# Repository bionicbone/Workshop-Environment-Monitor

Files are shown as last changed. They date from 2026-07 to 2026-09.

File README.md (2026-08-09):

# Workshop Environment Monitor (WEM)

An open-source ESP32-S3 based air quality and environmental monitor, built for workshops where 3D printing, soldering, and other fume-producing work happens in an enclosed space.

WEM continuously measures CO2, TVOC, HCHO (formaldehyde), particulates, temperature and humidity, displays live readings on a 7" touchscreen (if fitted), and publishes everything to [Home Assistant](https://www.home-assistant.io/) over MQTT for logging, automation and alerting.

This project exists because 3D printing ABS and soldering in a workshop produces measurable off-gassing and fumes — WEM was built to quantify that, and to benchmark a custom venting system against real data rather than guesswork.

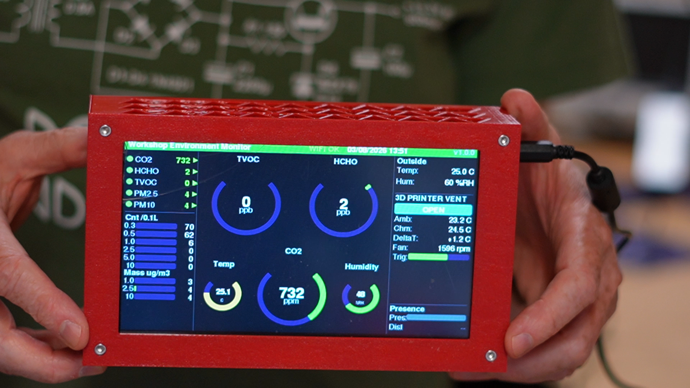
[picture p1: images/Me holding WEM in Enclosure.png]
WEM with Enclosure showing live sensor gauges


---

## Quality, and modular

These two ideas pull against each other, and how WEM resolves that is the main thing worth understanding about the design.

**Quality first.** WEM uses good sensors rather than the cheapest ones that will fit the footprint. A monitor that reports comfortable numbers while the air is actually bad is worse than no monitor at all — you'd act on it. That rules out the bargain modules, and it means a full build isn't cheap.

**So the build is modular.** Every sensor is optional, and so is the touchscreen. WEM probes what's connected at boot and adapts: absent hardware is excluded from the display, from the alarms, and from Home Assistant, with no code changes, no build flags, and nothing to configure.

The practical upshot: **start with the sensors that matter most to you and add the rest as you can afford them.** A WEM with two sensors and no screen is a legitimate build, not a broken one — and adding a sensor later is a matter of plugging it in and restarting.

## YouTube

Workshop Fumes Are Invisible — I Built a Monitor to See Them (https://youtu.be/jspVboeYZX0)

---

## Getting started

Everything you need is here: the firmware, the vendored libraries it builds against, the hardware design files, and a full [`USER_GUIDE.md`](USER_GUIDE.md) covering building, flashing, first boot and configuration.

**v1.0.0 is a compile-it-yourself release.** A compiled image has your WiFi and MQTT credentials baked into it, so there's no shared binary to download — you build the firmware from source against your own `secrets.h` and flash it to the ESP32-S3. [`USER_GUIDE.md`](USER_GUIDE.md) walks through the whole process, including the exact board settings and the vendored libraries you must build against.

A way to enter WiFi/MQTT details on the device at first boot is planned as a fast-follow — after which pre-built binaries can be published too.

---

## What it monitors

| Sensor | Measures | Interface |
|---|---|---|
| SGP30 | TVOC (total volatile organic compounds) | I2C |
| SFA40 | HCHO (formaldehyde) | UART |
| SCD40 | CO2 | I2C |
| SHT40 | Temperature / humidity (primary) | I2C |
| BME280 | Temperature / humidity (secondary, HA-only) | I2C |
| PMS5003 | Particulates — see below | UART |
| LD2410B | mmWave presence detection | UART |

### Particulates, in detail

The PMS5003 reports particulates two ways, and WEM publishes all nine channels to Home Assistant and to the display:

- **Particle counts** (cnt/0.1L) at **0.3, 0.5, 1.0, 2.5, 5.0 and 10 µm**
- **Mass concentrations** (µg/m³) at **PM1.0, PM2.5 and PM10**

**PM0.3 and PM0.5 are the ones to watch for 3D printing.** Ultrafine particles from a hot nozzle are numerous but individually almost weightless, so they can be present in large numbers while the mass figures still read close to zero. A monitor reporting only µg/m³ would tell you the air was fine. That's exactly the false-comfort problem the count channels exist to prevent — and a good illustration of why sensor choice matters more than sensor price.

Readings are shown on a 7" 800×480 SSD1963 TFT touchscreen (if fitted) with live gauges, and published to Home Assistant via [ArduinoHA](https://github.com/dawidchyrzynski/arduino-home-assistant) over MQTT.

---

## Running without a display

The touchscreen is optional on the same terms as the sensors — leave it off and WEM runs headless, reading every sensor and publishing to Home Assistant exactly as it otherwise would. It's the single biggest cost saving available, and a sensible build if you already live in the HA dashboard or you're mounting the unit somewhere nobody will look at it.

Two things to know before choosing that route: touch is currently WEM's only input, so a headless build **can't snooze an active alarm** and **can't clear the SGP30 calibration baseline**. Both will be exposed as Home Assistant buttons shortly after release. `USER_GUIDE.md` covers this fully.

---

## Repository structure

```
├── Workshop Environment Monitor/   Arduino sketch — the firmware source
├── hardware/                  PCB design files (Gerbers), STEP model, hardware README
│                              (attribution / Source Location notice), Bill of Materials,
│                              display manufacturer datasheet, breakout-board references
│                              (photos/links being added post-launch)
├── Libraries/                 Full vendored copies of every Arduino library WEM
│                              depends on, exactly as used to build and test it
├── stl for printing/          3D-printable enclosure and sensor mount STL files
├── images/                    Images used by the README, user guide and Bill of Materials
├── USER_GUIDE.md              Build, flash, first-boot and configuration guide
├── LICENSE                    Firmware licence (AGPL-3.0-or-later)
├── LICENSE-hardware.txt       Hardware licence (CERN-OHL-W-2.0)
├── THIRD_PARTY_LICENSES.md    Full attribution and licence text for every dependency
└── secrets.h.example          Template for your own WiFi/MQTT credentials
```

Copy `secrets.h.example` to `secrets.h` in the sketch folder and add your own WiFi/MQTT credentials before building — `secrets.h` is git-ignored and must never be committed. The user guide covers this.

---

## Building the PCB

Gerber files for the WEM main PCB are in [`hardware/`](hardware). To get boards made:

1. Download the Gerber `.zip` from `hardware/`.
2. Upload it directly to a fab house's quoting page — [JLCPCB](https://jlcpcb.com/).
3. Default settings (1.6mm thickness, HASL finish, 1oz copper) match what this design was built and tested with; nothing exotic is required.

Breakout-board module links and assembly photos are being put together for a launch video and will be added to `hardware/` shortly after release — see the note in that folder.

---

## Licensing

- **Firmware**: [AGPL-3.0-or-later](LICENSE) — required because WEM links against ArduinoHA, which is itself AGPL-3.0. See [`THIRD_PARTY_LICENSES.md`](THIRD_PARTY_LICENSES.md) for the full rationale and every dependency's licence.
- **Hardware (PCB + enclosure)**: [CERN-OHL-W-2.0](LICENSE-hardware.txt).

Full attribution for every third-party library, with verbatim licence text, is in [`THIRD_PARTY_LICENSES.md`](THIRD_PARTY_LICENSES.md).

---

## Why "Workshop" Environment Monitor?

Built to answer a simple question: is my workshop air actually safe to breathe while I'm printing ABS or soldering, and does my venting setup actually help? WEM logs real numbers to Home Assistant so that question has a real answer instead of a guess.

---

## Acknowledgements

Built with [ArduinoHA](https://github.com/dawidchyrzynski/arduino-home-assistant), [TFT_eSPI](https://github.com/Bodmer/TFT_eSPI), and sensor libraries from Adafruit and Sensirion. Full credits in [`THIRD_PARTY_LICENSES.md`](THIRD_PARTY_LICENSES.md).

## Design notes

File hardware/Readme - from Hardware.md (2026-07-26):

SPDX-License-Identifier: CERN-OHL-W-2.0

Copyright (C) 2026 Kevin Guest (BionicBone)

This documentation describes Open Hardware and is licensed under the
CERN-OHL-W v2 or any later version.

You may redistribute and modify this documentation and make products using it
under the terms of the CERN-OHL-W v2 (https://ohwr.org/cern-ohl-w-v2). This
documentation is distributed WITHOUT ANY EXPRESS OR IMPLIED WARRANTY, INCLUDING
OF MERCHANTABILITY, SATISFACTORY QUALITY AND FITNESS FOR A PARTICULAR PURPOSE.
Please see the CERN-OHL-W v2 for applicable conditions.

Source Location: https://github.com/bionicbone/Workshop-Environment-Monitor

---

Third-Party Material
---------------------

This folder includes the manufacturer datasheet for the TFT display module
used in this project. The datasheet is included for reference only, to help
builders identify and order the correct display variant (voltage, interface,
connector and options vary between otherwise similar-looking modules). It is
not authored by, and is not part of, the Covered Source above, and remains
the copyright of its original manufacturer. It is not licensed under
CERN-OHL-W-2.0.

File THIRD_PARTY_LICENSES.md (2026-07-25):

# Third-Party Licenses and Attribution

**Project:** Workshop Environmental Monitor (WEM)
**Copyright (C) 2026 Kevin Guest (TheBionicBone)**
**Project license:** AGPL-3.0-or-later — see [`LICENSE`](LICENSE)

---

## Why this project is AGPL-3.0

WEM links against **ArduinoHA** (`home-assistant-integration`), which is
distributed under the **GNU Affero General Public License v3.0**. Linking
produces a single combined work, so the AGPL's copyleft terms extend to the
whole firmware. The entire project is therefore released under AGPL-3.0-or-later.

**What this means for anyone using WEM:**

- You may use, study, modify and redistribute this firmware freely.
- If you distribute it — as source **or** as a compiled `.bin` — you must make
  the complete corresponding source available under the same license.
- Every binary published on this project's GitHub Releases page is accompanied
  by a link to the exact source tag it was built from, satisfying this
  requirement.

---

## Library summary

Versions correspond to those pinned in the Schematic Reference "Software /
Library Reference" table, verified identical under ESP32 Arduino core 2.0.17
and 3.3.10.

| Library | Version | Copyright holder | License |
|---|---|---|---|
| ArduinoHA (`home-assistant-integration`) | 2.1.0 | Dawid Chyrzynski | AGPL-3.0 |
| TFT_eSPI | 2.5.43 | Bodmer | BSD 2-Clause ("FreeBSD") |
| PubSubClient | 2.8 | Nicholas O'Leary | MIT |
| Adafruit SHT4x | 1.0.5 | Adafruit Industries | BSD 3-Clause |
| Adafruit SGP30 | 2.0.3 | Adafruit Industries | BSD 3-Clause |
| Adafruit BME280 | 2.3.0 | Limor Fried & Kevin Townsend, Adafruit Industries | BSD 3-Clause |
| Adafruit PM25AQI | 2.0.0 | Adafruit Industries | BSD 3-Clause |
| Adafruit Unified Sensor | 1.1.15 | Adafruit Industries | Apache-2.0 |
| Adafruit BusIO | 1.17.4 | Adafruit Industries | MIT |
| SensirionI2cScd4x | 1.1.0 | Sensirion AG | BSD 3-Clause |
| Sensirion Core | 0.7.3 | Sensirion AG | BSD 3-Clause |
| ld2410 (`ncmreynolds/ld2410`) | 0.2.2 | Nick Reynolds | LGPL-2.1 |
| ESP32 Arduino core (WiFi, Wire, SPI, FS, SPIFFS, ESPmDNS, ArduinoOTA, Preferences, Update) | 2.0.17 / 3.3.10 | Espressif Systems and contributors | LGPL-2.1-or-later |
| ESP-IDF (underlying SDK) | bundled with core | Espressif Systems | Apache-2.0 |

---

## Obligations, by license family

### AGPL-3.0 (ArduinoHA)
Complete corresponding source of the combined work must be available to
anyone who receives a binary. Satisfied by publishing full source on GitHub
and tagging each release binary against its source commit.

### LGPL-2.1 (ld2410, ESP32 Arduino core)
Source for the LGPL'd components must remain available, and users must be able
to relink the work against a modified version of those components. Satisfied
by publishing full source, documenting exact library and core versions, and
using unmodified upstream libraries. **Note:** if any LGPL library is ever
patched locally, that patched source must be published too.

### BSD 2/3-Clause (TFT_eSPI, Adafruit sensor libraries, Sensirion)
The copyright notice, conditions list and disclaimer must be reproduced in
redistributions — including binary-only ones. Reproduced in full below.

### MIT (PubSubClient, Adafruit BusIO)
The copyright notice and permission notice must be included in all copies or
substantial portions. Reproduced in full below.

### Apache-2.0 (Adafruit Unified Sensor, ESP-IDF)
A copy of the license must be included, any `NOTICE` file contents preserved,
and modified files marked as changed. No files from these components have been
modified in this project.

---

## Full license texts

> Verbatim `LICENSE` text from each upstream repository is reproduced below.
> Where an identical license *document* is shared, it appears once and the
> other users point to it: the GNU LGPL v2.1 text is given once (under ld2410)
> and referenced by the ESP32 core; the Apache-2.0 text is given once (under
> Adafruit Unified Sensor) and referenced by ESP-IDF. Each library's own
> copyright line is reproduced individually regardless.
>
> **Still outstanding before release:** the four Adafruit BSD-3-Clause libraries
> still carry four separate copies of the (identical) Adafruit BSD text — these
> could be consolidated the same way, or left as-is if the per-file Adafruit
> header blocks are being kept deliberately. Re-confirm each text against the
> upstream `LICENSE` at the pinned version, and check the ESP32 core version in
> the summary table (see note there).

### ArduinoHA — AGPL-3.0
Copyright (C) Dawid Chyrzynski
Source: https://github.com/dawidchyrzynski/arduino-home-assistant

                    GNU AFFERO GENERAL PUBLIC LICENSE
                       Version 3, 19 November 2007

 Copyright (C) 2007 Free Software Foundation, Inc. <https://fsf.org/>
 Everyone is permitted to copy and distribute verbatim copies
 of this license document, but changing it is not allowed.

                            Preamble

  The GNU Affero General Public License is a free, copyleft license for
software and other kinds of works, specifically designed to ensure
cooperation with the community in the case of network server software.

  The licenses for most software and other practical works are designed
to take away your freedom to share and change the works.  By contrast,
our General Public Licenses are intended to guarantee your freedom to
share and change all versions of a program--to make sure it remains free
software for all its users.

  When we speak of free software, we are referring to freedom, not
price.  Our General Public Licenses are designed to make sure that you
have the freedom to distribute copies of free software (and charge for
them if you wish), that you receive source code or can get it if you
want it, that you can change the software or use pieces of it in new
free programs, and that you know you can do these things.

  Developers that use our General Public Licenses protect your rights
with two steps: (1) assert copyright on the software, and (2) offer
you this License which gives you legal permission to copy, distribute
and/or modify the software.

  A secondary benefit of defending all users' freedom is that
improvements made in alternate versions of the program, if they
receive widespread use, become available for other developers to
incorporate.  Many developers of free software are heartened and
encouraged by the resulting cooperation.  However, in the case of
software used on network servers, this result may fail to come about.
The GNU General Public License permits making a modified version and
letting the public access it on a server without ever releasing its
source code to the public.

  The GNU Affero General Public License is designed specifically to
ensure that, in such cases, the modified source code becomes available
to the community.  It requires the operator of a network server to
provide the source code of the modified version running there to the
users of that server.  Therefore, public use of a modified version, on
a publicly accessible server, gives the public access to the source
code of the modified version.

  An older license, called the Affero General Public License and
published by Affero, was designed to accomplish similar goals.  This is
a different license, not a version of the Affero GPL, but Affero has
released a new version of the Affero GPL which permits relicensing under
this license.

  The precise terms and conditions for copying, distribution and
modification follow.

                       TERMS AND CONDITIONS

  0. Definitions.

  "This License" refers to version 3 of the GNU Affero General Public License.

  "Copyright" also means copyright-like laws that apply to other kinds of
works, such as semiconductor masks.

  "The Program" refers to any copyrightable work licensed under this
License.  Each licensee is addressed as "you".  "Licensees" and
"recipients" may be individuals or organizations.

  To "modify" a work means to copy from or adapt all or part of the work
in a fashion requiring copyright permission, other than the making of an
exact copy.  The resulting work is called a "modified version" of the
earlier work or a work "based on" the earlier work.

  A "covered work" means either the unmodified Program or a work based
on the Program.

  To "propagate" a work means to do anything with it that, without
permission, would make you directly or secondarily liable for
infringement under applicable copyright law, except executing it on a
computer or modifying a private copy.  Propagation includes copying,
distribution (with or without modification), making available to the
public, and in some countries other activities as well.

  To "convey" a work means any kind of propagation that enables other
parties to make or receive copies.  Mere interaction with a user through
a computer network, with no transfer of a copy, is not conveying.

  An interactive user interface displays "Appropriate Legal Notices"
to the extent that it includes a convenient and prominently visible
feature that (1) displays an appropriate copyright notice, and (2)
tells the user that there is no warranty for the work (except to the
extent that warranties are provided), that licensees may convey the
work under this License, and how to view a copy of this License.  If
the interface presents a list of user commands or options, such as a
menu, a prominent item in the list meets this criterion.

  1. Source Code.

  The "source code" for a work means the preferred form of the work
for making modifications to it.  "Object code" means any non-source
form of a work.

  A "Standard Interface" means an interface that either is an official
standard defined by a recognized standards body, or, in the case of
interfaces specified for a particular programming language, one that
is widely used among developers working in that language.

  The "System Libraries" of an executable work include anything, other
than the work as a whole, that (a) is included in the normal form of
packaging a Major Component, but which is not part of that Major
Component, and (b) serves only to enable use of the work with that
Major Component, or to implement a Standard Interface for which an
implementation is available to the public in source code form.  A
"Major Component", in this context, means a major essential component
(kernel, window system, and so on) of the specific operating system
(if any) on which the executable work runs, or a compiler used to
produce the work, or an object code interpreter used to run it.

  The "Corresponding Source" for a work in object code form means all
the source code needed to generate, install, and (for an executable
work) run the object code and to modify the work, including scripts to
control those activities.  However, it does not include the work's
System Libraries, or general-purpose tools or generally available free
programs which are used unmodified in performing those activities but
which are not part of the work.  For example, Corresponding Source
includes interface definition files associated with source files for
the work, and the source code for shared libraries and dynamically
linked subprograms that the work is specifically designed to require,
such as by intimate data communication or control flow between those
subprograms and other parts of the work.

  The Corresponding Source need not include anything that users
can regenerate automatically from other parts of the Corresponding
Source.

  The Corresponding Source for a work in source code form is that
same work.

  2. Basic Permissions.

  All rights granted under this License are granted for the term of
copyright on the Program, and are irrevocable provided the stated
conditions are met.  This License explicitly affirms your unlimited
permission to run the unmodified Program.  The output from running a
covered work is covered by this License only if the output, given its
content, constitutes a covered work.  This License acknowledges your
rights of fair use or other equivalent, as provided by copyright law.

  You may make, run and propagate covered works that you do not
convey, without conditions so long as your license otherwise remains
in force.  You may convey covered works to others for the sole purpose
of having them make modifications exclusively for you, or provide you
with facilities for running those works, provided that you comply with
the terms of this License in conveying all material for which you do
not control copyright.  Those thus making or running the covered works
for you must do so exclusively on your behalf, under your direction
and control, on terms that prohibit them from making any copies of
your copyrighted material outside their relationship with you.

  Conveying under any other circumstances is permitted solely under
the conditions stated below.  Sublicensing is not allowed; section 10
makes it unnecessary.

  3. Protecting Users' Legal Rights From Anti-Circumvention Law.

  No covered work shall be deemed part of an effective technological
measure under any applicable law fulfilling obligations under article
11 of the WIPO copyright treaty adopted on 20 December 1996, or
similar laws prohibiting or restricting circumvention of such
measures.

  When you convey a covered work, you waive any legal power to forbid
circumvention of technological measures to the extent such circumvention
is effected by exercising rights under this License with respect to
the covered work, and you disclaim any intention to limit operation or
modification of the work as a means of enforcing, against the work's
users, your or third parties' legal rights to forbid circumvention of
technological measures.

  4. Conveying Verbatim Copies.

  You may convey verbatim copies of the Program's source code as you
receive it, in any medium, provided that you conspicuously and
appropriately publish on each copy an appropriate copyright notice;
keep intact all notices stating that this License and any
non-permissive terms added in accord with section 7 apply to the code;
keep intact all notices of the absence of any warranty; and give all
recipients a copy of this License along with the Program.

  You may charge any price or no price for each copy that you convey,
and you may offer support or warranty protection for a fee.

  5. Conveying Modified Source Versions.

  You may convey a work based on the Program, or the modifications to
produce it from the Program, in the form of source code under the
terms of section 4, provided that you also meet all of these conditions:

    a) The work must carry prominent notices stating that you modified
    it, and giving a relevant date.

    b) The work must carry prominent notices stating that it is
    released under this License and any conditions added under section
    7.  This requirement modifies the requirement in section 4 to
    "keep intact all notices".

    c) You must license the entire work, as a whole, under this
    License to anyone who comes into possession of a copy.  This
    License will therefore apply, along with any applicable section 7
    additional terms, to the whole of the work, and all its parts,
    regardless of how they are packaged.  This License gives no
    permission to license the work in any other way, but it does not
    invalidate such permission if you have separately received it.

    d) If the work has interactive user interfaces, each must display
    Appropriate Legal Notices; however, if the Program has interactive
    interfaces that do not display Appropriate Legal Notices, your
    work need not make them do so.

  A compilation of a covered work with other separate and independent
works, which are not by their nature extensions of the covered work,
and which are not combined with it such as to form a larger program,
in or on a volume of a storage or distribution medium, is called an
"aggregate" if the compilation and its resulting copyright are not
used to limit the access or legal rights of the compilation's users
beyond what the individual works permit.  Inclusion of a covered work
in an aggregate does not cause this License to apply to the other
parts of the aggregate.

  6. Conveying Non-Source Forms.

  You may convey a covered work in object code form under the terms
of sections 4 and 5, provided that you also convey the
machine-readable Corresponding Source under the terms of this License,
in one of these ways:

    a) Convey the object code in, or embodied in, a physical product
    (including a physical distribution medium), accompanied by the
    Corresponding Source fixed on a durable physical medium
    customarily used for software interchange.

    b) Convey the object code in, or embodied in, a physical product
    (including a physical distribution medium), accompanied by a
    written offer, valid for at least three years and valid for as
    long as you offer spare parts or customer support for that product
    model, to give anyone who possesses the object code either (1) a
    copy of the Corresponding Source for all the software in the
    product that is covered by this License, on a durable physical
    medium customarily used for software interchange, for a price no
    more than your reasonable cost of physically performing this
    conveying of source, or (2) access to copy the
    Corresponding Source from a network server at no charge.

    c) Convey individual copies of the object code with a copy of the
    written offer to provide the Corresponding Source.  This
    alternative is allowed only occasionally and noncommercially, and
    only if you received the object code with such an offer, in accord
    with subsection 6b.

    d) Convey the object code by offering access from a designated
    place (gratis or for a charge), and offer equivalent access to the
    Corresponding Source in the same way through the same place at no
    further charge.  You need not require recipients to copy the
    Corresponding Source along with the object code.  If the place to
    copy the object code is a network server, the Corresponding Source
    may be on a different server (operated by you or a third party)
    that supports equivalent copying facilities, provided you maintain
    clear directions next to the object code saying where to find the
    Corresponding Source.  Regardless of what server hosts the
    Corresponding Source, you remain obligated to ensure that it is
    available for as long as needed to satisfy these requirements.

    e) Convey the object code using peer-to-peer transmission, provided
    you inform other peers where the object code and Corresponding
    Source of the work are being offered to the general public at no
    charge under subsection 6d.

  A separable portion of the object code, whose source code is excluded
from the Corresponding Source as a System Library, need not be
included in conveying the object code work.

  A "User Product" is either (1) a "consumer product", which means any
tangible personal property which is normally used for personal, family,
or household purposes, or (2) anything designed or sold for incorporation
into a dwelling.  In determining whether a product is a consumer product,
doubtful cases shall be resolved in favor of coverage.  For a particular
product received by a particular user, "normally used" refers to a
typical or common use of that class of product, regardless of the status
of the particular user or of the way in which the particular user
actually uses, or expects or is expected to use, the product.  A product
is a consumer product regardless of whether the product has substantial
commercial, industrial or non-consumer uses, unless such uses represent
the only significant mode of use of the product.

  "Installation Information" for a User Product means any methods,
procedures, authorization keys, or other information required to install
and execute modified versions of a covered work in that User Product from
a modified version of its Corresponding Source.  The information must
suffice to ensure that the continued functioning of the modified object
code is in no case prevented or interfered with solely because
modification has been made.

  If you convey an object code work under this section in, or with, or
specifically for use in, a User Product, and the conveying occurs as
part of a transaction in which the right of possession and use of the
User Product is transferred to the recipient in perpetuity or for a
fixed term (regardless of how the transaction is characterized), the
Corresponding Source conveyed under this section must be accompanied
by the Installation Information.  But this requirement does not apply
if neither you nor any third party retains the ability to install
modified object code on the User Product (for example, the work has
been installed in ROM).

  The requirement to provide Installation Information does not include a
requirement to continue to provide support service, warranty, or updates
for a work that has been modified or installed by the recipient, or for
the User Product in which it has been modified or installed.  Access to a
network may be denied when the modification itself materially and
adversely affects the operation of the network or violates the rules and
protocols for communication across the network.

  Corresponding Source conveyed, and Installation Information provided,
in accord with this section must be in a format that is publicly
documented (and with an implementation available to the public in
source code form), and must require no special password or key for
unpacking, reading or copying.

  7. Additional Terms.

  "Additional permissions" are terms that supplement the terms of this
License by making exceptions from one or more of its conditions.
Additional permissions that are applicable to the entire Program shall
be treated as though they were included in this License, to the extent
that they are valid under applicable law.  If additional permissions
apply only to part of the Program, that part may be used separately
under those permissions, but the entire Program remains governed by
this License without regard to the additional permissions.

  When you convey a copy of a covered work, you may at your option
remove any additional permissions from that copy, or from any part of
it.  (Additional permissions may be written to require their own
removal in certain cases when you modify the work.)  You may place
additional permissions on material, added by you to a covered work,
for which you have or can give appropriate copyright permission.

  Notwithstanding any other provision of this License, for material you
add to a covered work, you may (if authorized by the copyright holders of
that material) supplement the terms of this License with terms:

    a) Disclaiming warranty or limiting liability differently from the
    terms of sections 15 and 16 of this License; or

    b) Requiring preservation of specified reasonable legal notices or
    author attributions in that material or in the Appropriate Legal
    Notices displayed by works containing it; or

    c) Prohibiting misrepresentation of the origin of that material, or
    requiring that modified versions of such material be marked in
    reasonable ways as different from the original version; or

    d) Limiting the use for publicity purposes of names of licensors or
    authors of the material; or

    e) Declining to grant rights under trademark law for use of some
    trade names, trademarks, or service marks; or

    f) Requiring indemnification of licensors and authors of that
    material by anyone who conveys the material (or modified versions of
    it) with contractual assumptions of liability to the recipient, for
    any liability that these contractual assumptions directly impose on
    those licensors and authors.

  All other non-permissive additional terms are considered "further
restrictions" within the meaning of section 10.  If the Program as you
received it, or any part of it, contains a notice stating that it is
governed by this License along with a term that is a further
restriction, you may remove that term.  If a license document contains
a further restriction but permits relicensing or conveying under this
License, you may add to a covered work material governed by the terms
of that license document, provided that the further restriction does
not survive such relicensing or conveying.

  If you add terms to a covered work in accord with this section, you
must place, in the relevant source files, a statement of the
additional terms that apply to those files, or a notice indicating
where to find the applicable terms.

  Additional terms, permissive or non-permissive, may be stated in the
form of a separately written license, or stated as exceptions;
the above requirements apply either way.

  8. Termination.

  You may not propagate or modify a covered work except as expressly
provided under this License.  Any attempt otherwise to propagate or
modify it is void, and will automatically terminate your rights under
this License (including any patent licenses granted under the third
paragraph of section 11).

  However, if you cease all violation of this License, then your
license from a particular copyright holder is reinstated (a)
provisionally, unless and until the copyright holder explicitly and
finally terminates your license, and (b) permanently, if the copyright
holder fails to notify you of the violation by some reasonable means
prior to 60 days after the cessation.

  Moreover, your license from a particular copyright holder is
reinstated permanently if the copyright holder notifies you of the
violation by some reasonable means, this is the first time you have
received notice of violation of this License (for any work) from that
copyright holder, and you cure the violation prior to 30 days after
your receipt of the notice.

  Termination of your rights under this section does not terminate the
licenses of parties who have received copies or rights from you under
this License.  If your rights have been terminated and not permanently
reinstated, you do not qualify to receive new licenses for the same
material under section 10.

  9. Acceptance Not Required for Having Copies.

  You are not required to accept this License in order to receive or
run a copy of the Program.  Ancillary propagation of a covered work
occurring solely as a consequence of using peer-to-peer transmission
to receive a copy likewise does not require acceptance.  However,
nothing other than this License grants you permission to propagate or
modify any covered work.  These actions infringe copyright if you do
not accept this License.  Therefore, by modifying or propagating a
covered work, you indicate your acceptance of this License to do so.

  10. Automatic Licensing of Downstream Recipients.

  Each time you convey a covered work, the recipient automatically
receives a license from the original licensors, to run, modify and
propagate that work, subject to this License.  You are not responsible
for enforcing compliance by third parties with this License.

  An "entity transaction" is a transaction transferring control of an
organization, or substantially all assets of one, or subdividing an
organization, or merging organizations.  If propagation of a covered
work results from an entity transaction, each party to that
transaction who receives a copy of the work also receives whatever
licenses to the work the party's predecessor in interest had or could
give under the previous paragraph, plus a right to possession of the
Corresponding Source of the work from the predecessor in interest, if
the predecessor has it or can get it with reasonable efforts.

  You may not impose any further restrictions on the exercise of the
rights granted or affirmed under this License.  For example, you may
not impose a license fee, royalty, or other charge for exercise of
rights granted under this License, and you may not initiate litigation
(including a cross-claim or counterclaim in a lawsuit) alleging that
any patent claim is infringed by making, using, selling, offering for
sale, or importing the Program or any portion of it.

  11. Patents.

  A "contributor" is a copyright holder who authorizes use under this
License of the Program or a work on which the Program is based.  The
work thus licensed is called the contributor's "contributor version".

  A contributor's "essential patent claims" are all patent claims
owned or controlled by the contributor, whether already acquired or
hereafter acquired, that would be infringed by some manner, permitted
by this License, of making, using, or selling its contributor version,
but do not include claims that would be infringed only as a
consequence of further modification of the contributor version.  For
purposes of this definition, "control" includes the right to grant
patent sublicenses in a manner consistent with the requirements of
this License.

  Each contributor grants you a non-exclusive, worldwide, royalty-free
patent license under the contributor's essential patent claims, to
make, use, sell, offer for sale, import and otherwise run, modify and
propagate the contents of its contributor version.

  In the following three paragraphs, a "patent license" is any express
agreement or commitment, however denominated, not to enforce a patent
(such as an express permission to practice a patent or covenant not to
sue for patent infringement).  To "grant" such a patent license to a
party means to make such an agreement or commitment not to enforce a
patent against the party.

  If you convey a covered work, knowingly relying on a patent license,
and the Corresponding Source of the work is not available for anyone
to copy, free of charge and under the terms of this License, through a
publicly available network server or other readily accessible means,
then you must either (1) cause the Corresponding Source to be so
available, or (2) arrange to deprive yourself of the benefit of the
patent license for this particular work, or (3) arrange, in a manner
consistent with the requirements of this License, to extend the patent
license to downstream recipients.  "Knowingly relying" means you have
actual knowledge that, but for the patent license, your conveying the
covered work in a country, or your recipient's use of the covered work
in a country, would infringe one or more identifiable patents in that
country that you have reason to believe are valid.

  If, pursuant to or in connection with a single transaction or
arrangement, you convey, or propagate by procuring conveyance of, a
covered work, and grant a patent license to some of the parties
receiving the covered work authorizing them to use, propagate, modify
or convey a specific copy of the covered work, then the patent license
you grant is automatically extended to all recipients of the covered
work and works based on it.

  A patent license is "discriminatory" if it does not include within
the scope of its coverage, prohibits the exercise of, or is
conditioned on the non-exercise of one or more of the rights that are
specifically granted under this License.  You may not convey a covered
work if you are a party to an arrangement with a third party that is
in the business of distributing software, under which you make payment
to the third party based on the extent of your activity of conveying
the work, and under which the third party grants, to any of the
parties who would receive the covered work from you, a discriminatory
patent license (a) in connection with copies of the covered work
conveyed by you (or copies made from those copies), or (b) primarily
for and in connection with specific products or compilations that
contain the covered work, unless you entered into that arrangement,
or that patent license was granted, prior to 28 March 2007.

  Nothing in this License shall be construed as excluding or limiting
any implied license or other defenses to infringement that may
otherwise be available to you under applicable patent law.

  12. No Surrender of Others' Freedom.

  If conditions are imposed on you (whether by court order, agreement or
otherwise) that contradict the conditions of this License, they do not
excuse you from the conditions of this License.  If you cannot convey a
covered work so as to satisfy simultaneously your obligations under this
License and any other pertinent obligations, then as a consequence you may
not convey it at all.  For example, if you agree to terms that obligate you
to collect a royalty for further conveying from those to whom you convey
the Program, the only way you could satisfy both those terms and this
License would be to refrain entirely from conveying the Program.

  13. Remote Network Interaction; Use with the GNU General Public License.

  Notwithstanding any other provision of this License, if you modify the
Program, your modified version must prominently offer all users
interacting with it remotely through a computer network (if your version
supports such interaction) an opportunity to receive the Corresponding
Source of your version by providing access to the Corresponding Source
from a network server at no charge, through some standard or customary
means of facilitating copying of software.  This Corresponding Source
shall include the Corresponding Source for any work covered by version 3
of the GNU General Public License that is incorporated pursuant to the
following paragraph.

  Notwithstanding any other provision of this License, you have
permission to link or combine any covered work with a work licensed
under version 3 of the GNU General Public License into a single
combined work, and to convey the resulting work.  The terms of this
License will continue to apply to the part which is the covered work,
but the work with which it is combined will remain governed by version
3 of the GNU General Public License.

  14. Revised Versions of this License.

  The Free Software Foundation may publish revised and/or new versions of
the GNU Affero General Public License from time to time.  Such new versions
will be similar in spirit to the present version, but may differ in detail to
address new problems or concerns.

  Each version is given a distinguishing version number.  If the
Program specifies that a certain numbered version of the GNU Affero General
Public License "or any later version" applies to it, you have the
option of following the terms and conditions either of that numbered
version or of any later version published by the Free Software
Foundation.  If the Program does not specify a version number of the
GNU Affero General Public License, you may choose any version ever published
by the Free Software Foundation.

  If the Program specifies that a proxy can decide which future
versions of the GNU Affero General Public License can be used, that proxy's
public statement of acceptance of a version permanently authorizes you
to choose that version for the Program.

  Later license versions may give you additional or different
permissions.  However, no additional obligations are imposed on any
author or copyright holder as a result of your choosing to follow a
later version.

  15. Disclaimer of Warranty.

  THERE IS NO WARRANTY FOR THE PROGRAM, TO THE EXTENT PERMITTED BY
APPLICABLE LAW.  EXCEPT WHEN OTHERWISE STATED IN WRITING THE COPYRIGHT
HOLDERS AND/OR OTHER PARTIES PROVIDE THE PROGRAM "AS IS" WITHOUT WARRANTY
OF ANY KIND, EITHER EXPRESSED OR IMPLIED, INCLUDING, BUT NOT LIMITED TO,
THE IMPLIED WARRANTIES OF MERCHANTABILITY AND FITNESS FOR A PARTICULAR
PURPOSE.  THE ENTIRE RISK AS TO THE QUALITY AND PERFORMANCE OF THE PROGRAM
IS WITH YOU.  SHOULD THE PROGRAM PROVE DEFECTIVE, YOU ASSUME THE COST OF
ALL NECESSARY SERVICING, REPAIR OR CORRECTION.

  16. Limitation of Liability.

  IN NO EVENT UNLESS REQUIRED BY APPLICABLE LAW OR AGREED TO IN WRITING
WILL ANY COPYRIGHT HOLDER, OR ANY OTHER PARTY WHO MODIFIES AND/OR CONVEYS
THE PROGRAM AS PERMITTED ABOVE, BE LIABLE TO YOU FOR DAMAGES, INCLUDING ANY
GENERAL, SPECIAL, INCIDENTAL OR CONSEQUENTIAL DAMAGES ARISING OUT OF THE
USE OR INABILITY TO USE THE PROGRAM (INCLUDING BUT NOT LIMITED TO LOSS OF
DATA OR DATA BEING RENDERED INACCURATE OR LOSSES SUSTAINED BY YOU OR THIRD
PARTIES OR A FAILURE OF THE PROGRAM TO OPERATE WITH ANY OTHER PROGRAMS),
EVEN IF SUCH HOLDER OR OTHER PARTY HAS BEEN ADVISED OF THE POSSIBILITY OF
SUCH DAMAGES.

  17. Interpretation of Sections 15 and 16.

  If the disclaimer of warranty and limitation of liability provided
above cannot be given local legal effect according to their terms,
reviewing courts shall apply local law that most closely approximates
an absolute waiver of all civil liability in connection with the
Program, unless a warranty or assumption of liability accompanies a
copy of the Program in return for a fee.

                     END OF TERMS AND CONDITIONS

            How to Apply These Terms to Your New Programs

  If you develop a new program, and you want it to be of the greatest
possible use to the public, the best way to achieve this is to make it
free software which everyone can redistribute and change under these terms.

  To do so, attach the following notices to the program.  It is safest
to attach them to the start of each source file to most effectively
state the exclusion of warranty; and each file should have at least
the "copyright" line and a pointer to where the full notice is found.

    <one line to give the program's name and a brief idea of what it does.>
    Copyright (C) <year>  <name of author>

    This program is free software: you can redistribute it and/or modify
    it under the terms of the GNU Affero General Public License as published
    by the Free Software Foundation, either version 3 of the License, or
    (at your option) any later version.

    This program is distributed in the hope that it will be useful,
    but WITHOUT ANY WARRANTY; without even the implied warranty of
    MERCHANTABILITY or FITNESS FOR A PARTICULAR PURPOSE.  See the
    GNU Affero General Public License for more details.

    You should have received a copy of the GNU Affero General Public License
    along with this program.  If not, see <https://www.gnu.org/licenses/>.

Also add information on how to contact you by electronic and paper mail.

  If your software can interact with users remotely through a computer
network, you should also make sure that it provides a way for users to
get its source.  For example, if your program is a web application, its
interface could display a "Source" link that leads users to an archive
of the code.  There are many ways you could offer source, and different
solutions will be better for different programs; see section 13 for the
specific requirements.

  You should also get your employer (if you work as a programmer) or school,
if any, to sign a "copyright disclaimer" for the program, if necessary.
For more information on this, and how to apply and follow the GNU AGPL, see
<https://www.gnu.org/licenses/>.

---

### TFT_eSPI — BSD 2-Clause (FreeBSD License)
Copyright (c) 2023 Bodmer (https://github.com/Bodmer)
All rights reserved.

The original starting point for this library was the Adafruit_ILI9341
library in January 2015.

The licence for that library is MIT.

The first evolution of the library that led to TFT_eSPI is recorded here:

https://www.instructables.com/id/Arduino-TFT-display-and-font-library/

Adafruit_ILI9341 ORIGINAL LIBRARY HEADER:

vvvvvvvvvvvvvvvvvvvvvvvvvvvvvvvvvvStartvvvvvvvvvvvvvvvvvvvvvvvvvvvvvvvvvvv
  This is our library for the Adafruit  ILI9341 Breakout and Shield
  ----> http://www.adafruit.com/products/1651

  Check out the links above for our tutorials and wiring diagrams
  These displays use SPI to communicate, 4 or 5 pins are required to
  interface (RST is optional)
  Adafruit invests time and resources providing this open source code,
  please support Adafruit and open-source hardware by purchasing
  products from Adafruit!

  Written by Limor Fried/Ladyada for Adafruit Industries.
  MIT license, all text above must be included in any redistribution
  
^^^^^^^^^^^^^^^^^^^^^^^^^^^^^^^^^^^End^^^^^^^^^^^^^^^^^^^^^^^^^^^^^^^^^^^^

Selected functions from the Adafruit_GFX library (as it was in 2015) have
been imported into the TFT_eSPI.cpp file and modified to improve
performance, add features and make them compatible with the ESP8266 and
ESP32.

The fonts from the Adafruit_GFX and Button functions were added later.
The fonts can be found with the license.txt file in the "Fonts\GFXFF"
folder.

The Adafruit_GFX functions are covered by the BSD licence.

Adafruit_GFX ORIGINAL LIBRARY LICENSE:

vvvvvvvvvvvvvvvvvvvvvvvvvvvvvvvvvvStartvvvvvvvvvvvvvvvvvvvvvvvvvvvvvvvvvvv

Software License Agreement (BSD License)

Copyright (c) 2012 Adafruit Industries.  All rights reserved.

Redistribution and use in source and binary forms, with or without
modification, are permitted provided that the following conditions are met:

- Redistributions of source code must retain the above copyright notice,
  this list of conditions and the following disclaimer.
- Redistributions in binary form must reproduce the above copyright notice,
  this list of conditions and the following disclaimer in the documentation
  and/or other materials provided with the distribution.

THIS SOFTWARE IS PROVIDED BY THE COPYRIGHT HOLDERS AND CONTRIBUTORS "AS IS"
AND ANY EXPRESS OR IMPLIED WARRANTIES, INCLUDING, BUT NOT LIMITED TO, THE
IMPLIED WARRANTIES OF MERCHANTABILITY AND FITNESS FOR A PARTICULAR PURPOSE
ARE DISCLAIMED. IN NO EVENT SHALL THE COPYRIGHT HOLDER OR CONTRIBUTORS BE
LIABLE FOR ANY DIRECT, INDIRECT, INCIDENTAL, SPECIAL, EXEMPLARY, OR
CONSEQUENTIAL DAMAGES (INCLUDING, BUT NOT LIMITED TO, PROCUREMENT OF
SUBSTITUTE GOODS OR SERVICES; LOSS OF USE, DATA, OR PROFITS; OR BUSINESS
INTERRUPTION) HOWEVER CAUSED AND ON ANY THEORY OF LIABILITY, WHETHER IN
CONTRACT, STRICT LIABILITY, OR TORT (INCLUDING NEGLIGENCE OR OTHERWISE)
ARISING IN ANY WAY OUT OF THE USE OF THIS SOFTWARE, EVEN IF ADVISED OF THE
POSSIBILITY OF SUCH DAMAGE.

^^^^^^^^^^^^^^^^^^^^^^^^^^^^^^^^^^^End^^^^^^^^^^^^^^^^^^^^^^^^^^^^^^^^^^^^

Due to the evolution of the TFT_eSPI library the original code may no longer
be recognisable, however in most cases the function names can be used as a
reference point since the aim is to retain a level of compatibility with
the popular Adafruit_GFX graphics functions.

Contributions from other authors are recorded on GitHub:
https://github.com/Bodmer/TFT_eSPI

The major addition to the original library was the addition of fast
rendering proportional fonts of different sizes as documented here:

https://www.instructables.com/id/Arduino-TFT-display-and-font-library/

The larger fonts are "Run Length Encoded (RLE)", this was done to
reduce the font memory footprint for AVR processors that have limited
FLASH, with the added benefit of a significant improvement in rendering
speed.

In 2016 the library evolved significantly to support the ESP8266 and then
the ESP32. In 2017 new Touch Screen functions were added and a new Sprite
class called TFT_eSprite to permit "flicker free" screen updates of complex
graphics.

In 2018 anti-aliased fonts were added along with a Processing font conversion
sketch.

In 2019 the library was adapted to be able to use it with any 32-bit Arduino
compatible processor. It will run on 8-bit and 16-bit processors but will be
slow due to extensive use of 32-bit variables.

Many of the example sketches are original work that contain code created
for my own projects. For all the original code the FreeBSD licence applies
and is compatible with the GNU GPL.

vvvvvvvvvvvvvvvvvvvvvvvvvvvvvvvvvvStartvvvvvvvvvvvvvvvvvvvvvvvvvvvvvvvvvvv
Software License Agreement (FreeBSD License)

Copyright (c) 2023 Bodmer (https://github.com/Bodmer)

All rights reserved.

Redistribution and use in source and binary forms, with or without
modification, are permitted provided that the following conditions are met:

1. Redistributions of source code must retain the above copyright notice, this
   list of conditions and the following disclaimer.
2. Redistributions in binary form must reproduce the above copyright notice,
   this list of conditions and the following disclaimer in the documentation
   and/or other materials provided with the distribution.

THIS SOFTWARE IS PROVIDED BY THE COPYRIGHT HOLDERS AND CONTRIBUTORS "AS IS" AND
ANY EXPRESS OR IMPLIED WARRANTIES, INCLUDING, BUT NOT LIMITED TO, THE IMPLIED
WARRANTIES OF MERCHANTABILITY AND FITNESS FOR A PARTICULAR PURPOSE ARE
DISCLAIMED. IN NO EVENT SHALL THE COPYRIGHT OWNER OR CONTRIBUTORS BE LIABLE FOR
ANY DIRECT, INDIRECT, INCIDENTAL, SPECIAL, EXEMPLARY, OR CONSEQUENTIAL DAMAGES
(INCLUDING, BUT NOT LIMITED TO, PROCUREMENT OF SUBSTITUTE GOODS OR SERVICES;
LOSS OF USE, DATA, OR PROFITS; OR BUSINESS INTERRUPTION) HOWEVER CAUSED AND
ON ANY THEORY OF LIABILITY, WHETHER IN CONTRACT, STRICT LIABILITY, OR TORT
(INCLUDING NEGLIGENCE OR OTHERWISE) ARISING IN ANY WAY OUT OF THE USE OF THIS
SOFTWARE, EVEN IF ADVISED OF THE POSSIBILITY OF SUCH DAMAGE.

The views and conclusions contained in the software and documentation are those
of the authors and should not be interpreted as representing official policies,
either expressed or implied, of the FreeBSD Project.
^^^^^^^^^^^^^^^^^^^^^^^^^^^^^^^^^^^End^^^^^^^^^^^^^^^^^^^^^^^^^^^^^^^^^^^^

---

### PubSubClient — MIT
Copyright (c) 2008-2020 Nicholas O'Leary
Source: https://github.com/knolleary/pubsubclient

Copyright (c) 2008-2020 Nicholas O'Leary

Permission is hereby granted, free of charge, to any person obtaining
a copy of this software and associated documentation files (the
"Software"), to deal in the Software without restriction, including
without limitation the rights to use, copy, modify, merge, publish,
distribute, sublicense, and/or sell copies of the Software, and to
permit persons to whom the Software is furnished to do so, subject to
the following conditions:

The above copyright notice and this permission notice shall be
included in all copies or substantial portions of the Software.

THE SOFTWARE IS PROVIDED "AS IS", WITHOUT WARRANTY OF ANY KIND,
EXPRESS OR IMPLIED, INCLUDING BUT NOT LIMITED TO THE WARRANTIES OF
MERCHANTABILITY, FITNESS FOR A PARTICULAR PURPOSE AND
NONINFRINGEMENT. IN NO EVENT SHALL THE AUTHORS OR COPYRIGHT HOLDERS BE
LIABLE FOR ANY CLAIM, DAMAGES OR OTHER LIABILITY, WHETHER IN AN ACTION
OF CONTRACT, TORT OR OTHERWISE, ARISING FROM, OUT OF OR IN CONNECTION
WITH THE SOFTWARE OR THE USE OR OTHER DEALINGS IN THE SOFTWARE.

---

### Adafruit libraries — BSD 3-Clause
Covers: Adafruit SHT4x, Adafruit SGP30, Adafruit BME280, Adafruit PM25AQI

Copyright (c) Adafruit Industries
Copyright (c) 2015 Limor Fried & Kevin Townsend for Adafruit Industries (BME280)
All rights reserved.

Software License Agreement (BSD License)

Copyright (c) 2012, Adafruit Industries
All rights reserved.

Redistribution and use in source and binary forms, with or without
modification, are permitted provided that the following conditions are met:
1. Redistributions of source code must retain the above copyright
notice, this list of conditions and the following disclaimer.
2. Redistributions in binary form must reproduce the above copyright
notice, this list of conditions and the following disclaimer in the
documentation and/or other materials provided with the distribution.
3. Neither the name of the copyright holders nor the
names of its contributors may be used to endorse or promote products
derived from this software without specific prior written permission.

THIS SOFTWARE IS PROVIDED BY THE COPYRIGHT HOLDERS ''AS IS'' AND ANY
EXPRESS OR IMPLIED WARRANTIES, INCLUDING, BUT NOT LIMITED TO, THE IMPLIED
WARRANTIES OF MERCHANTABILITY AND FITNESS FOR A PARTICULAR PURPOSE ARE
DISCLAIMED. IN NO EVENT SHALL THE COPYRIGHT HOLDER BE LIABLE FOR ANY
DIRECT, INDIRECT, INCIDENTAL, SPECIAL, EXEMPLARY, OR CONSEQUENTIAL DAMAGES
(INCLUDING, BUT NOT LIMITED TO, PROCUREMENT OF SUBSTITUTE GOODS OR SERVICES;
LOSS OF USE, DATA, OR PROFITS; OR BUSINESS INTERRUPTION) HOWEVER CAUSED AND
ON ANY THEORY OF LIABILITY, WHETHER IN CONTRACT, STRICT LIABILITY, OR TORT
(INCLUDING NEGLIGENCE OR OTHERWISE) ARISING IN ANY WAY OUT OF THE USE OF THIS
SOFTWARE, EVEN IF ADVISED OF THE POSSIBILITY OF SUCH DAMAGE.

/*!
 *  @file Adafruit_SHT4x.cpp
 *
 *  @mainpage Adafruit SHT4x Digital Humidity & Temp Sensor
 *
 *  @section intro_sec Introduction
 *
 *  This is a library for the SHT4x Digital Humidity & Temp Sensor
 *
 *  Designed specifically to work with the SHT4x Digital sensor from Adafruit
 *
 *  Pick one up today in the adafruit shop!
 *  ------> https://www.adafruit.com/product/4885
 *
 *  These sensors use I2C to communicate, 2 pins are required to interface
 *
 *  Adafruit invests time and resources providing this open source code,
 *  please support Adafruit andopen-source hardware by purchasing products
 *  from Adafruit!
 *
 *  @section author Author
 *
 *  Limor Fried/Ladyada (Adafruit Industries).
 *
 *  @section license License
 *
 *  BSD license, all text above must be included in any redistribution
 */
 
 /*!
 *  @file Adafruit_SHT4x.h
 *
 *  This is a library for the SHT4x Digital Humidity & Temp Sensor
 *
 *  Designed specifically to work with the SHT4x Humidity & Temp Sensor
 *  -----> https://www.adafruit.com/product/4885
 *
 *  These sensors use I2C to communicate, 2 pins are required to interface
 *
 *  Adafruit invests time and resources providing this open source code,
 *  please support Adafruit andopen-source hardware by purchasing products
 *  from Adafruit!
 *
 *  Limor Fried/Ladyada (Adafruit Industries).
 *
 *  BSD license, all text above must be included in any redistribution
 */

/*!
 * @file Adafruit_SGP30.cpp
 *
 * @mainpage Adafruit SGP30 gas sensor driver
 *
 * @section intro_sec Introduction
 *
 * This is the documentation for Adafruit's SGP30 driver for the
 * Arduino platform.  It is designed specifically to work with the
 * Adafruit SGP30 breakout: http://www.adafruit.com/products/3709
 *
 * These sensors use I2C to communicate, 2 pins (SCL+SDA) are required
 * to interface with the breakout.
 *
 * Adafruit invests time and resources providing this open source code,
 * please support Adafruit and open-source hardware by purchasing
 * products from Adafruit!
 *
 *
 * @section author Author
 * Written by Ladyada for Adafruit Industries.
 *
 * @section license License
 * BSD license, all text here must be included in any redistribution.
 *
 */
 
 /*!
 * @file Adafruit_SGP30.h
 *
 * This is the documentation for Adafruit's SGP30 driver for the
 * Arduino platform.  It is designed specifically to work with the
 * Adafruit SGP30 breakout: http://www.adafruit.com/products/3709
 *
 * These sensors use I2C to communicate, 2 pins (SCL+SDA) are required
 * to interface with the breakout.
 *
 * Adafruit invests time and resources providing this open source code,
 * please support Adafruit and open-source hardware by purchasing
 * products from Adafruit!
 *
 * Written by Ladyada for Adafruit Industries.
 *
 * BSD license, all text here must be included in any redistribution.
 *
 */

/*!
 * @file Adafruit_BME280.cpp
 *
 * @mainpage Adafruit BME280 humidity, temperature & pressure sensor
 *
 * @section intro_sec Introduction
 *
 *  Driver for the BME280 humidity, temperature & pressure sensor
 *
 * These sensors use I2C or SPI to communicate, 2 or 4 pins are required
 * to interface.
 *
 * Designed specifically to work with the Adafruit BME280 Breakout
 * ----> http://www.adafruit.com/products/2652
 *
 *  Adafruit invests time and resources providing this open source code,
 *  please support Adafruit and open-source hardware by purchasing
 *  products from Adafruit!
 *
 * @section author Author
 *
 * Written by Kevin "KTOWN" Townsend for Adafruit Industries.
 *
 * @section license License
 *
 * BSD license, all text here must be included in any redistribution.
 * See the LICENSE file for details.
 *
 */
 
 /*!
 * @file Adafruit_BME280.h
 *
 * Designed specifically to work with the Adafruit BME280 Breakout
 * ----> http://www.adafruit.com/products/2650
 *
 * These sensors use I2C or SPI to communicate, 2 or 4 pins are required
 * to interface.
 *
 * Adafruit invests time and resources providing this open source code,
 * please support Adafruit and open-source hardware by purchasing
 * products from Adafruit!
 *
 * Written by Kevin "KTOWN" Townsend for Adafruit Industries.
 *
 * BSD license, all text here must be included in any redistribution.
 * See the LICENSE file for details.
 *
 */

/*!
 * @file Adafruit_AQIUtils.cpp
 *
 * Adafruit invests time and resources providing this open source code,
 * please support Adafruit and open-source hardware by purchasing
 * products from Adafruit!
 *
 *
 * @section author Author
 * Written by Ladyada for Adafruit Industries.
 * Modified by Brent Rubell for Adafruit Industries
 *
 * @section license License
 * BSD license, all text here must be included in any redistribution.
 *
 */
 
 /*!
 * @file Adafruit_AQIUtils.h
 *
 * Adafruit invests time and resources providing this open source code,
 * please support Adafruit and open-source hardware by purchasing
 * products from Adafruit!
 *
 *
 * @section author Author
 * Written by Ladyada for Adafruit Industries.
 * Modified by Brent Rubell for Adafruit Industries
 *
 * @section license License
 * BSD license, all text here must be included in any redistribution.
 *
 */
 
 /*!
 * @file Adafruit_PM25AQI.cpp
 *
 * @mainpage Adafruit PM2.5 air quality sensor driver
 *
 * @section intro_sec Introduction
 *
 * This is the documentation for Adafruit's PM2.5 AQI driver for the
 * Arduino platform.  It is designed specifically to work with the
 * Adafruit PM2.5 Air quality sensors: http://www.adafruit.com/products/4632
 *
 * This library also works with the Cubic PM1006 UART Air Quality Sensor.
 *
 * These sensors use I2C or UART to communicate.
 *
 * Adafruit invests time and resources providing this open source code,
 * please support Adafruit and open-source hardware by purchasing
 * products from Adafruit!
 *
 *
 * @section author Author
 * Written by Ladyada for Adafruit Industries.
 * Modified by Brent Rubell for Adafruit Industries for use with Cubic PM1006
 * Air Quality Sensor.
 *
 * @section license License
 * BSD license, all text here must be included in any redistribution.
 *
 */
 
 /*!
 * @file Adafruit_PM25AQI.h
 *
 * This is the documentation for Adafruit's PM25 AQI driver for the
 * Arduino platform.  It is designed specifically to work with the
 * Adafruit PM25 air quality sensors: http://www.adafruit.com/products/4632
 *
 * These sensors use I2C or UART to communicate.
 *
 * Adafruit invests time and resources providing this open source code,
 * please support Adafruit and open-source hardware by purchasing
 * products from Adafruit!
 *
 * Written by Ladyada for Adafruit Industries.
 *
 * BSD license, all text here must be included in any redistribution.
 *
 */

 NOTE: No header block found in Adafruit_PM25AQI_I2C.cpp v2.0.0

 /*!
 * @file Adafruit_PM25AQI_I2C.h
 *
 * This is the documentation for Adafruit's PM25 AQI driver for the
 * Arduino platform.  It is designed specifically to work with the
 * Adafruit PM25 air quality sensors: http://www.adafruit.com/products/4632
 *
 * These sensors use I2C or UART to communicate.
 *
 * Adafruit invests time and resources providing this open source code,
 * please support Adafruit and open-source hardware by purchasing
 * products from Adafruit!
 *
 * Written by Ladyada for Adafruit Industries.
 *
 * BSD license, all text here must be included in any redistribution.
 *
 */

 /*!
 * @file Adafruit_PM25AQI_UART.cpp
 *
 * Adafruit invests time and resources providing this open source code,
 * please support Adafruit and open-source hardware by purchasing
 * products from Adafruit!
 *
 *
 * @section author Author
 * Written by Ladyada for Adafruit Industries.
 * Modified by Brent Rubell for Adafruit Industries
 *
 * @section license License
 * BSD license, all text here must be included in any redistribution.
 *
 */
 
 /*!
 * @file Adafruit_PM25AQI_UART.h
 *
 * This is the documentation for Adafruit's PM25 AQI driver for the
 * Arduino platform.  It is designed specifically to work with the
 * Adafruit PM25 air quality sensors: http://www.adafruit.com/products/4632
 *
 * These sensors use I2C or UART to communicate.
 *
 * Adafruit invests time and resources providing this open source code,
 * please support Adafruit and open-source hardware by purchasing
 * products from Adafruit!
 *
 * Written by Ladyada for Adafruit Industries.
 *
 * BSD license, all text here must be included in any redistribution.
 *
 */

> Adafruit's own note: *"BSD license, all text here must be included in any
> redistribution."* Reproduce their header block, not just the LICENSE file.

---

### Adafruit BusIO — MIT
Copyright (c) Adafruit Industries

The MIT License (MIT)

Copyright (c) 2017 Adafruit Industries

Permission is hereby granted, free of charge, to any person obtaining a copy
of this software and associated documentation files (the "Software"), to deal
in the Software without restriction, including without limitation the rights
to use, copy, modify, merge, publish, distribute, sublicense, and/or sell
copies of the Software, and to permit persons to whom the Software is
furnished to do so, subject to the following conditions:

The above copyright notice and this permission notice shall be included in all
copies or substantial portions of the Software.

THE SOFTWARE IS PROVIDED "AS IS", WITHOUT WARRANTY OF ANY KIND, EXPRESS OR
IMPLIED, INCLUDING BUT NOT LIMITED TO THE WARRANTIES OF MERCHANTABILITY,
FITNESS FOR A PARTICULAR PURPOSE AND NONINFRINGEMENT. IN NO EVENT SHALL THE
AUTHORS OR COPYRIGHT HOLDERS BE LIABLE FOR ANY CLAIM, DAMAGES OR OTHER
LIABILITY, WHETHER IN AN ACTION OF CONTRACT, TORT OR OTHERWISE, ARISING FROM,
OUT OF OR IN CONNECTION WITH THE SOFTWARE OR THE USE OR OTHER DEALINGS IN THE
SOFTWARE.

---

### Adafruit Unified Sensor — Apache-2.0
Copyright (c) Adafruit Industries

                                 Apache License
                           Version 2.0, January 2004
                        http://www.apache.org/licenses/

   TERMS AND CONDITIONS FOR USE, REPRODUCTION, AND DISTRIBUTION

   1. Definitions.

      "License" shall mean the terms and conditions for use, reproduction,
      and distribution as defined by Sections 1 through 9 of this document.

      "Licensor" shall mean the copyright owner or entity authorized by
      the copyright owner that is granting the License.

      "Legal Entity" shall mean the union of the acting entity and all
      other entities that control, are controlled by, or are under common
      control with that entity. For the purposes of this definition,
      "control" means (i) the power, direct or indirect, to cause the
      direction or management of such entity, whether by contract or
      otherwise, or (ii) ownership of fifty percent (50%) or more of the
      outstanding shares, or (iii) beneficial ownership of such entity.

      "You" (or "Your") shall mean an individual or Legal Entity
      exercising permissions granted by this License.

      "Source" form shall mean the preferred form for making modifications,
      including but not limited to software source code, documentation
      source, and configuration files.

      "Object" form shall mean any form resulting from mechanical
      transformation or translation of a Source form, including but
      not limited to compiled object code, generated documentation,
      and conversions to other media types.

      "Work" shall mean the work of authorship, whether in Source or
      Object form, made available under the License, as indicated by a
      copyright notice that is included in or attached to the work
      (an example is provided in the Appendix below).

      "Derivative Works" shall mean any work, whether in Source or Object
      form, that is based on (or derived from) the Work and for which the
      editorial revisions, annotations, elaborations, or other modifications
      represent, as a whole, an original work of authorship. For the purposes
      of this License, Derivative Works shall not include works that remain
      separable from, or merely link (or bind by name) to the interfaces of,
      the Work and Derivative Works thereof.

      "Contribution" shall mean any work of authorship, including
      the original version of the Work and any modifications or additions
      to that Work or Derivative Works thereof, that is intentionally
      submitted to Licensor for inclusion in the Work by the copyright owner
      or by an individual or Legal Entity authorized to submit on behalf of
      the copyright owner. For the purposes of this definition, "submitted"
      means any form of electronic, verbal, or written communication sent
      to the Licensor or its representatives, including but not limited to
      communication on electronic mailing lists, source code control systems,
      and issue tracking systems that are managed by, or on behalf of, the
      Licensor for the purpose of discussing and improving the Work, but
      excluding communication that is conspicuously marked or otherwise
      designated in writing by the copyright owner as "Not a Contribution."

      "Contributor" shall mean Licensor and any individual or Legal Entity
      on behalf of whom a Contribution has been received by Licensor and
      subsequently incorporated within the Work.

   2. Grant of Copyright License. Subject to the terms and conditions of
      this License, each Contributor hereby grants to You a perpetual,
      worldwide, non-exclusive, no-charge, royalty-free, irrevocable
      copyright license to reproduce, prepare Derivative Works of,
      publicly display, publicly perform, sublicense, and distribute the
      Work and such Derivative Works in Source or Object form.

   3. Grant of Patent License. Subject to the terms and conditions of
      this License, each Contributor hereby grants to You a perpetual,
      worldwide, non-exclusive, no-charge, royalty-free, irrevocable
      (except as stated in this section) patent license to make, have made,
      use, offer to sell, sell, import, and otherwise transfer the Work,
      where such license applies only to those patent claims licensable
      by such Contributor that are necessarily infringed by their
      Contribution(s) alone or by combination of their Contribution(s)
      with the Work to which such Contribution(s) was submitted. If You
      institute patent litigation against any entity (including a
      cross-claim or counterclaim in a lawsuit) alleging that the Work
      or a Contribution incorporated within the Work constitutes direct
      or contributory patent infringement, then any patent licenses
      granted to You under this License for that Work shall terminate
      as of the date such litigation is filed.

   4. Redistribution. You may reproduce and distribute copies of the
      Work or Derivative Works thereof in any medium, with or without
      modifications, and in Source or Object form, provided that You
      meet the following conditions:

      (a) You must give any other recipients of the Work or
          Derivative Works a copy of this License; and

      (b) You must cause any modified files to carry prominent notices
          stating that You changed the files; and

      (c) You must retain, in the Source form of any Derivative Works
          that You distribute, all copyright, patent, trademark, and
          attribution notices from the Source form of the Work,
          excluding those notices that do not pertain to any part of
          the Derivative Works; and

      (d) If the Work includes a "NOTICE" text file as part of its
          distribution, then any Derivative Works that You distribute must
          include a readable copy of the attribution notices contained
          within such NOTICE file, excluding those notices that do not
          pertain to any part of the Derivative Works, in at least one
          of the following places: within a NOTICE text file distributed
          as part of the Derivative Works; within the Source form or
          documentation, if provided along with the Derivative Works; or,
          within a display generated by the Derivative Works, if and
          wherever such third-party notices normally appear. The contents
          of the NOTICE file are for informational purposes only and
          do not modify the License. You may add Your own attribution
          notices within Derivative Works that You distribute, alongside
          or as an addendum to the NOTICE text from the Work, provided
          that such additional attribution notices cannot be construed
          as modifying the License.

      You may add Your own copyright statement to Your modifications and
      may provide additional or different license terms and conditions
      for use, reproduction, or distribution of Your modifications, or
      for any such Derivative Works as a whole, provided Your use,
      reproduction, and distribution of the Work otherwise complies with
      the conditions stated in this License.

   5. Submission of Contributions. Unless You explicitly state otherwise,
      any Contribution intentionally submitted for inclusion in the Work
      by You to the Licensor shall be under the terms and conditions of
      this License, without any additional terms or conditions.
      Notwithstanding the above, nothing herein shall supersede or modify
      the terms of any separate license agreement you may have executed
      with Licensor regarding such Contributions.

   6. Trademarks. This License does not grant permission to use the trade
      names, trademarks, service marks, or product names of the Licensor,
      except as required for reasonable and customary use in describing the
      origin of the Work and reproducing the content of the NOTICE file.

   7. Disclaimer of Warranty. Unless required by applicable law or
      agreed to in writing, Licensor provides the Work (and each
      Contributor provides its Contributions) on an "AS IS" BASIS,
      WITHOUT WARRANTIES OR CONDITIONS OF ANY KIND, either express or
      implied, including, without limitation, any warranties or conditions
      of TITLE, NON-INFRINGEMENT, MERCHANTABILITY, or FITNESS FOR A
      PARTICULAR PURPOSE. You are solely responsible for determining the
      appropriateness of using or redistributing the Work and assume any
      risks associated with Your exercise of permissions under this License.

   8. Limitation of Liability. In no event and under no legal theory,
      whether in tort (including negligence), contract, or otherwise,
      unless required by applicable law (such as deliberate and grossly
      negligent acts) or agreed to in writing, shall any Contributor be
      liable to You for damages, including any direct, indirect, special,
      incidental, or consequential damages of any character arising as a
      result of this License or out of the use or inability to use the
      Work (including but not limited to damages for loss of goodwill,
      work stoppage, computer failure or malfunction, or any and all
      other commercial damages or losses), even if such Contributor
      has been advised of the possibility of such damages.

   9. Accepting Warranty or Additional Liability. While redistributing
      the Work or Derivative Works thereof, You may choose to offer,
      and charge a fee for, acceptance of support, warranty, indemnity,
      or other liability obligations and/or rights consistent with this
      License. However, in accepting such obligations, You may act only
      on Your own behalf and on Your sole responsibility, not on behalf
      of any other Contributor, and only if You agree to indemnify,
      defend, and hold each Contributor harmless for any liability
      incurred by, or claims asserted against, such Contributor by reason
      of your accepting any such warranty or additional liability.

   END OF TERMS AND CONDITIONS

   APPENDIX: How to apply the Apache License to your work.

      To apply the Apache License to your work, attach the following
      boilerplate notice, with the fields enclosed by brackets "[]"
      replaced with your own identifying information. (Don't include
      the brackets!)  The text should be enclosed in the appropriate
      comment syntax for the file format. We also recommend that a
      file or class name and description of purpose be included on the
      same "printed page" as the copyright notice for easier
      identification within third-party archives.

   Copyright [yyyy] [name of copyright owner]

   Licensed under the Apache License, Version 2.0 (the "License");
   you may not use this file except in compliance with the License.
   You may obtain a copy of the License at

       http://www.apache.org/licenses/LICENSE-2.0

   Unless required by applicable law or agreed to in writing, software
   distributed under the License is distributed on an "AS IS" BASIS,
   WITHOUT WARRANTIES OR CONDITIONS OF ANY KIND, either express or implied.
   See the License for the specific language governing permissions and
   limitations under the License.

/*
 * Copyright (C) 2008 The Android Open Source Project
 *
 * Licensed under the Apache License, Version 2.0 (the "License");
 * you may not use this file except in compliance with the License.
 * You may obtain a copy of the License at
 *
 * http://www.apache.org/licenses/LICENSE-2.0
 *
 * Unless required by applicable law or agreed to in writing, software< /span>
 * distributed under the License is distributed on an "AS IS" BASIS,
 * WITHOUT WARRANTIES OR CONDITIONS OF ANY KIND, either express or implied.
 * See the License for the specific language governing permissions and
 * limitations under the License.
 */

/* Update by K. Townsend (Adafruit Industries) for lighter typedefs, and
 * extended sensor support to include color, voltage and current */

---

### Sensirion (SensirionI2cScd4x, Sensirion Core) — BSD 3-Clause
Copyright (c) Sensirion AG, Switzerland
All rights reserved.

BSD 3-Clause License

Copyright (c) 2025, Sensirion AG
All rights reserved.

Redistribution and use in source and binary forms, with or without
modification, are permitted provided that the following conditions are met:

1. Redistributions of source code must retain the above copyright notice, this
   list of conditions and the following disclaimer.

2. Redistributions in binary form must reproduce the above copyright notice,
   this list of conditions and the following disclaimer in the documentation
   and/or other materials provided with the distribution.

3. Neither the name of the copyright holder nor the names of its
   contributors may be used to endorse or promote products derived from
   this software without specific prior written permission.

THIS SOFTWARE IS PROVIDED BY THE COPYRIGHT HOLDERS AND CONTRIBUTORS "AS IS"
AND ANY EXPRESS OR IMPLIED WARRANTIES, INCLUDING, BUT NOT LIMITED TO, THE
IMPLIED WARRANTIES OF MERCHANTABILITY AND FITNESS FOR A PARTICULAR PURPOSE ARE
DISCLAIMED. IN NO EVENT SHALL THE COPYRIGHT HOLDER OR CONTRIBUTORS BE LIABLE
FOR ANY DIRECT, INDIRECT, INCIDENTAL, SPECIAL, EXEMPLARY, OR CONSEQUENTIAL
DAMAGES (INCLUDING, BUT NOT LIMITED TO, PROCUREMENT OF SUBSTITUTE GOODS OR
SERVICES; LOSS OF USE, DATA, OR PROFITS; OR BUSINESS INTERRUPTION) HOWEVER
CAUSED AND ON ANY THEORY OF LIABILITY, WHETHER IN CONTRACT, STRICT LIABILITY,
OR TORT (INCLUDING NEGLIGENCE OR OTHERWISE) ARISING IN ANY WAY OUT OF THE USE
OF THIS SOFTWARE, EVEN IF ADVISED OF THE POSSIBILITY OF SUCH DAMAGE.

/*
 * THIS FILE IS AUTOMATICALLY GENERATED
 *
 * Generator:     sensirion-driver-generator 1.1.2
 * Product:       scd4x
 * Model-Version: 2.0
 */
/*
 * Copyright (c) 2025, Sensirion AG
 * All rights reserved.
 *
 * Redistribution and use in source and binary forms, with or without
 * modification, are permitted provided that the following conditions are met:
 *
 * * Redistributions of source code must retain the above copyright notice, this
 *   list of conditions and the following disclaimer.
 *
 * * Redistributions in binary form must reproduce the above copyright notice,
 *   this list of conditions and the following disclaimer in the documentation
 *   and/or other materials provided with the distribution.
 *
 * * Neither the name of Sensirion AG nor the names of its
 *   contributors may be used to endorse or promote products derived from
 *   this software without specific prior written permission.
 *
 * THIS SOFTWARE IS PROVIDED BY THE COPYRIGHT HOLDERS AND CONTRIBUTORS "AS IS"
 * AND ANY EXPRESS OR IMPLIED WARRANTIES, INCLUDING, BUT NOT LIMITED TO, THE
 * IMPLIED WARRANTIES OF MERCHANTABILITY AND FITNESS FOR A PARTICULAR PURPOSE
 * ARE DISCLAIMED. IN NO EVENT SHALL THE COPYRIGHT HOLDER OR CONTRIBUTORS BE
 * LIABLE FOR ANY DIRECT, INDIRECT, INCIDENTAL, SPECIAL, EXEMPLARY, OR
 * CONSEQUENTIAL DAMAGES (INCLUDING, BUT NOT LIMITED TO, PROCUREMENT OF
 * SUBSTITUTE GOODS OR SERVICES; LOSS OF USE, DATA, OR PROFITS; OR BUSINESS
 * INTERRUPTION) HOWEVER CAUSED AND ON ANY THEORY OF LIABILITY, WHETHER IN
 * CONTRACT, STRICT LIABILITY, OR TORT (INCLUDING NEGLIGENCE OR OTHERWISE)
 * ARISING IN ANY WAY OUT OF THE USE OF THIS SOFTWARE, EVEN IF ADVISED OF THE
 * POSSIBILITY OF SUCH DAMAGE.
 */
 
---
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

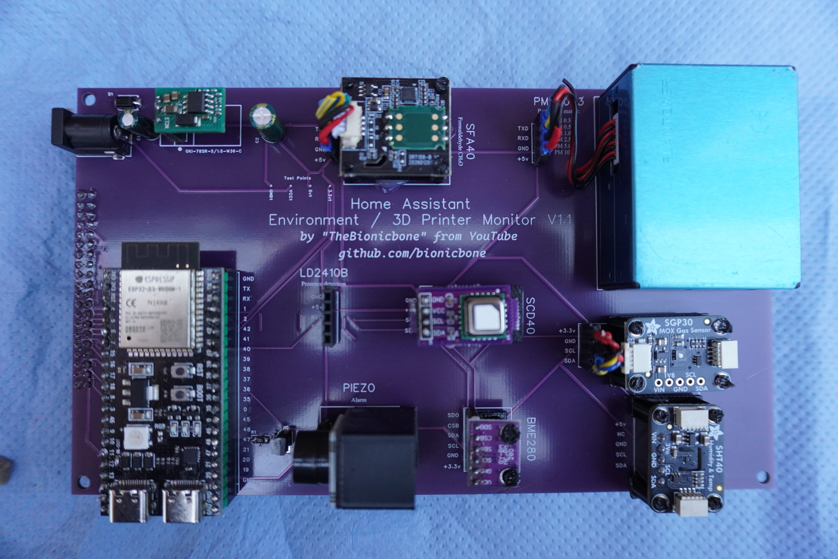
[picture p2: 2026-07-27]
images/WEM PCB V1.1 Populated.JPG

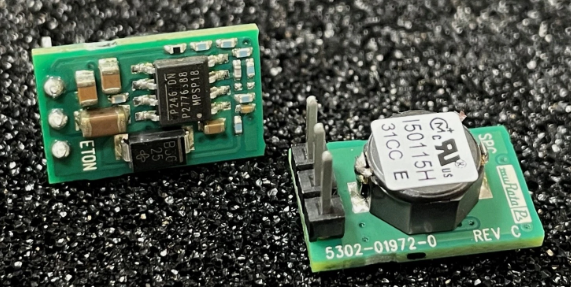
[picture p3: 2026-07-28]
images/OKI-78SR-5__1_5-W36H-C.png

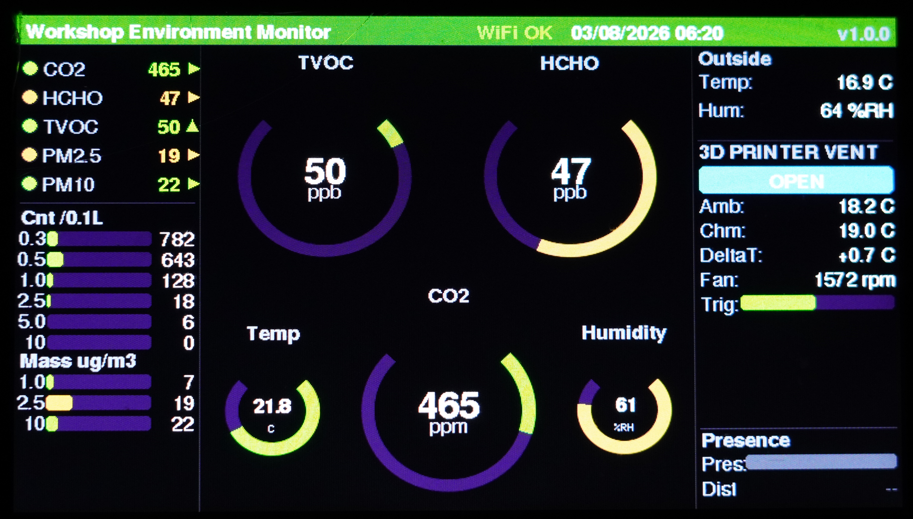
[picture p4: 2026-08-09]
images/display-teaser.png

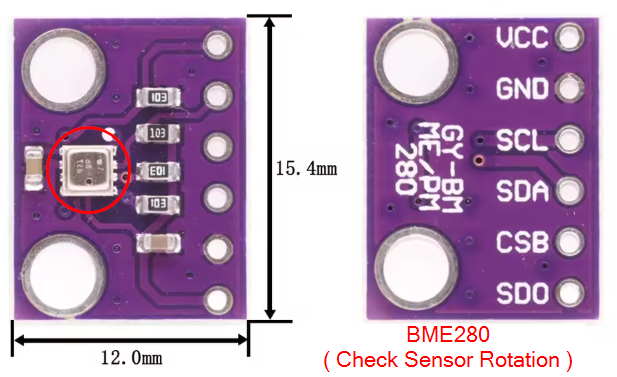
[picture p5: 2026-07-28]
images/BME280.png

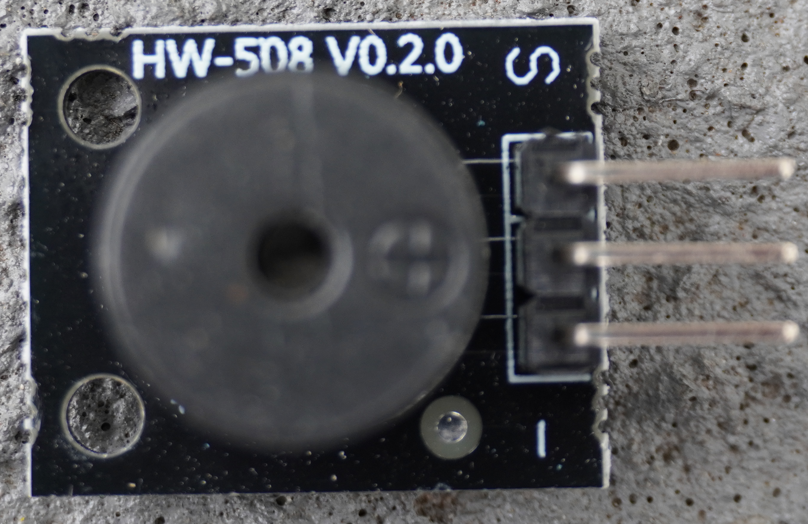
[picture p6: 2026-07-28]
images/3-pin passive piezo buzzer.png

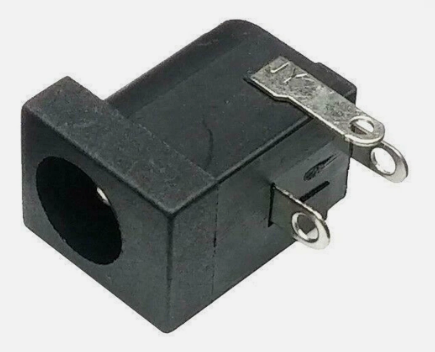
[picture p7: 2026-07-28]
images/DC-005-2.5-W.png

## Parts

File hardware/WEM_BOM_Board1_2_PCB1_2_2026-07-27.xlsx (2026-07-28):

Quantity | Comment | Designator | Requirement | Link to Picture | Part Tested & Validated
 | MUST HAVE Parts
1 | PCB (order from JLCPCB) - Minimum order qty is 5 | PCB | Required | https://github.com/bionicbone/Workshop-Environment-Monitor/blob/main/images/WEM%20PCB%20V1.1%20Populated.JPG | https://jlcpcb.com/ (click order now and just upload the Gerber file in the hardware folder of the project)
1 | HEADER 2.54 20x2 Female | TFT Connection | Required | https://github.com/bionicbone/Workshop-Environment-Monitor/blob/main/images/HEADER%202.54%2020x2%20Female.png | https://www.amazon.co.uk/TIKATARER-Connector-Current-Transmission-Connection/dp/B0GRWYGTPT
3 | HEADER 2.54 40x1 Female | All sensors & ESP32-S3 Connections | Required | https://github.com/bionicbone/Workshop-Environment-Monitor/blob/main/images/HEADER%202.54%2040x1%20Female.png | https://www.amazon.co.uk/2-54mm-Straight-Single-Female-Headers-Black/dp/B00899WQ6U
1 | ESP32-S3-N16R8 DevKitC, 2x22 0.1in headers - MATCH THE PHOTO EXACTLY, do not substitute. Check all four: (1) RGB LED on pin 48 AND disconnectable by 0 ohm resistor or solder jumper - pin 48 is the display Data/Command line in this design; (2) USB chip is CH343P; (3) 5V disconnectable by 0 ohm resistor or solder jumper; (4) all pin markings and component layout as shown. PSRAM must be left DISABLED in the build config - GPIO 35 and 36 depend on it. Not all ESP32-S3s are the same - many fakes out there. | MCU | Required | https://github.com/bionicbone/Workshop-Environment-Monitor/blob/main/images/ESP32-S3%20Correct%20One.png | https://www.aliexpress.com/item/1005008752956562.html
1 | 3-pin "passive" piezo buzzer | Passive Buzzer (not active type) | Required | https://github.com/bionicbone/Workshop-Environment-Monitor/blob/main/images/3-pin%20passive%20piezo%20buzzer.png | https://www.aliexpress.com/item/1005007592230799.html
1 | 2N2222A Transistor | Q1 Buzzer Circuit | Required | https://github.com/bionicbone/Workshop-Environment-Monitor/blob/main/images/2N2222A%20Transistor.png | https://www.aliexpress.com/item/1005009744071978.html
1 | 10kΩ — 1206 SMD | R1 Buzzer Circuit | Required | https://github.com/bionicbone/Workshop-Environment-Monitor/blob/main/images/10k%20Size%201206%20SMD%20Resistor.png | https://www.ebay.co.uk/itm/283238400288?var=583685471859
 | In usefulness vs budget order - although at least one sensor makes sense :)
1 | Adafruit SGP30 TVOC Sensor - Adafruit ONLY - Many Clones Cause Issues! | Refer to pictures to ensure correct one | Optional | https://github.com/bionicbone/Workshop-Environment-Monitor/blob/main/images/Adafruit%20SGP30%20ONLY.png | https://thepihut.com/products/adafruit-sgp30-air-quality-sensor-breakout-voc-and-eco2-ada3709
1 | Plantower PMS5003 Particle Sensor - PLANTOWER ONLY - Many Clones! | Refer to pictures to ensure correct one | Optional | https://github.com/bionicbone/Workshop-Environment-Monitor/blob/main/images/Plantower%20PMS5003%20Particle%20Sensor%20ONLY.png | https://www.aliexpress.com/item/1005005319820316.html
1 | Adafruit SHT40 Temperature & Humidity Sensor - Adafruit ONLY - Many Clones! | Refer to pictures to ensure correct one | Optional | https://github.com/bionicbone/Workshop-Environment-Monitor/blob/main/images/Adafruit%20SHT40%20ONLY.png | https://thepihut.com/products/adafruit-sensirion-sht40-temperature-humidity-sensor-stemma-qt-qwiic
1 | Sensirion SFA40 Formaldehyde Sensor Breakout Board | Refer to pictures to ensure correct one | Optional | https://github.com/bionicbone/Workshop-Environment-Monitor/blob/main/images/SFA40%20Breakout%20Board.png | https://www.aliexpress.com/item/1005009129454282.html
1 | LD2410B 24GHz Radar Sensor | Refer to pictures to ensure correct one | Optional | https://github.com/bionicbone/Workshop-Environment-Monitor/blob/main/images/LD2410B.png | https://www.aliexpress.com/item/1005006233732333.html
1 | SCD40 CO₂ Sensor | Refer to pictures to ensure correct one | Optional | https://github.com/bionicbone/Workshop-Environment-Monitor/blob/main/images/SCD40%20Breakout%20Board.png | https://www.aliexpress.com/item/1005004251901089.html
1 | BME280 Air Pressure Sensor 3.3V version - DATA ONLY AVAILABLE IN Home Assistant | Refer to pictures to ensure correct one | Optional | https://github.com/bionicbone/Workshop-Environment-Monitor/blob/main/images/BME280.png | https://www.aliexpress.com/item/1005009492867829.html
 | Data visibility (optional depending on use-case)
1 | TFT Display (Display data Locally) 7" TFT Screen Touch LCD Display Module w/SSD1963 Controller Board,MCU (from buydisplay see exact ordering details on GitHub project page) | TFT | Optional | https://github.com/bionicbone/Workshop-Environment-Monitor/blob/main/images/7%20inch%20TFT%20Captive%20Touch%20Display%20with%20SSD1963.png | https://www.buydisplay.com/7-tft-screen-touch-lcd-display-module-w-ssd1963-controller-board-mcu
1 | Raspberry Pi 3 (Display data in Home Assistant) | Home Assistant (HA) Connection | Optional | HA is user-specific | Consider Raspberry Pi 3, Pi 4 / Pi 5 depending on what you expect your Home Assistant to process
 | Powering (1 method required)
 | -- Method 1 - Recommended
1 | Any old laptop power block that outputs between 9V and 35V will do | Power Supply | Required for Method 1 | None | None
1 | OKI-78SR-5/1.5-W36H-C DC-DC converter 5V smooth output | Refer to pictures to ensure correct one |  | https://github.com/bionicbone/Workshop-Environment-Monitor/blob/main/images/OKI-78SR-5__1_5-W36H-C.png | https://www.ebay.co.uk/itm/155949855428
1 | SS34 (SMD Size) 40V/3A Schottky Diode | D1 |  | https://github.com/bionicbone/Workshop-Environment-Monitor/blob/main/images/SS34%20SMD%20Schottky%20Diode.png | Search eBay
1 | 47uF 25V Low-ESR Capacitor | C1 |  | https://github.com/bionicbone/Workshop-Environment-Monitor/blob/main/images/47uF%2025v%20LowESR%20Capacitor.png | Search eBay
1 | 100uF 25V Low-ESR Capacitor | C2 |  | https://github.com/bionicbone/Workshop-Environment-Monitor/blob/main/images/100uF%2025v%20LowESR%20Capacitor.png | Search eBay
1 | DC-005-2.5-W (2.5mm x 5.5mm DC power barrel jack socket, PCB mount connector) | DC1 |  | https://github.com/bionicbone/Workshop-Environment-Monitor/blob/main/images/DC-005-2.5-W.png | https://www.ebay.co.uk/itm/223635135504?var=522366646906
1 | MALE DC Power Barrel Jack Connector 2.5mm x 5.5mm | DC2 |  | https://github.com/bionicbone/Workshop-Environment-Monitor/blob/main/images/Power%20Barrel%20Jack%20Connector%202_1mm%20x%205_5mm.png | https://www.ebay.co.uk/itm/113391679701
 | -- Method 2 - Possible
1 | Very good quality USB-C power adaptor capable of 5V @ 2A - 10W (depending on optional items used) | Will have random crashes / reboots if not powered correctly | Optional | https://github.com/bionicbone/Workshop-Environment-Monitor/blob/main/images/USB%20Power%20Tested%205v%202A%2010W.png
1 | Very good quality USB-C to USB-C Cable 100W Tested | Will have random crashes / reboots if a long / poor quality cable is used |  | https://github.com/bionicbone/Workshop-Environment-Monitor/blob/main/images/USB%20Power%20Tested%205v%202A%2010W.png

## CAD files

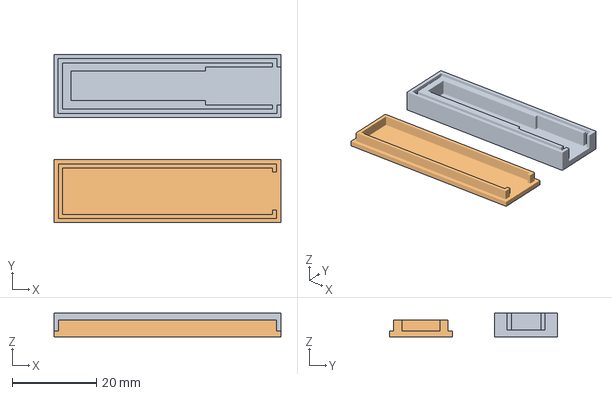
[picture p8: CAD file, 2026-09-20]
stl for printing/LD2410B_Mount_v3.3mf
54.0 x 40.0 x 5.60 mm
LD2410B_Mount_Body_v3.step
LD2410B_Mount_Top_v3.step

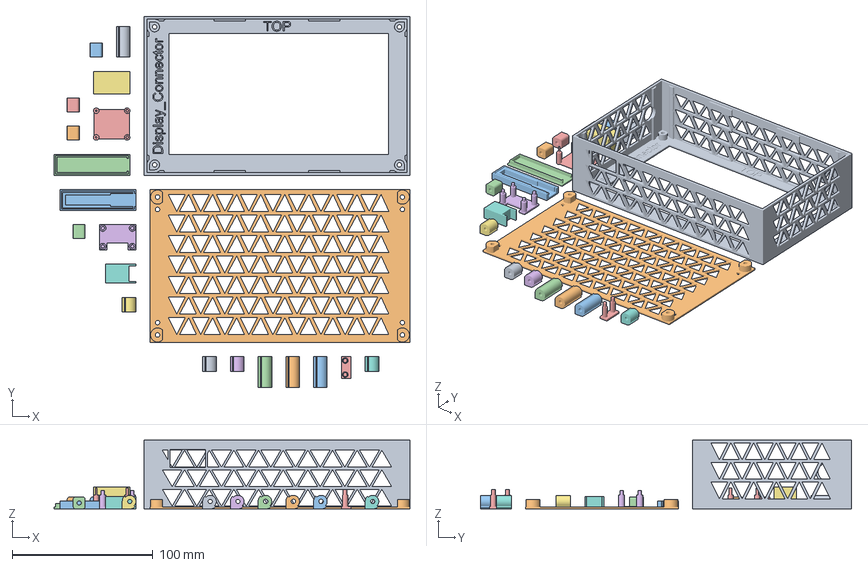
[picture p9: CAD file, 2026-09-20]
stl for printing/WEM Enclosure v17.3mf
253.0 x 263.8 x 49.0 mm
WEM Enclosure Body v17.step
WEM Enclosure Back v7.step
LD2410B_Mount_Body_v3.step
LD2410B_Mount_Top_v3.step
SFA40 Mount v6.step
SGP30 SHT40 Mount v2.step
Buzzer Mount v1.step
SCD40 Mount v2.step
WEM PCB Fixing v6.step x 4
BME280 Mount v2.step
WEM Display Fixing v8.step x 4
WEM Foot v2.step x 4

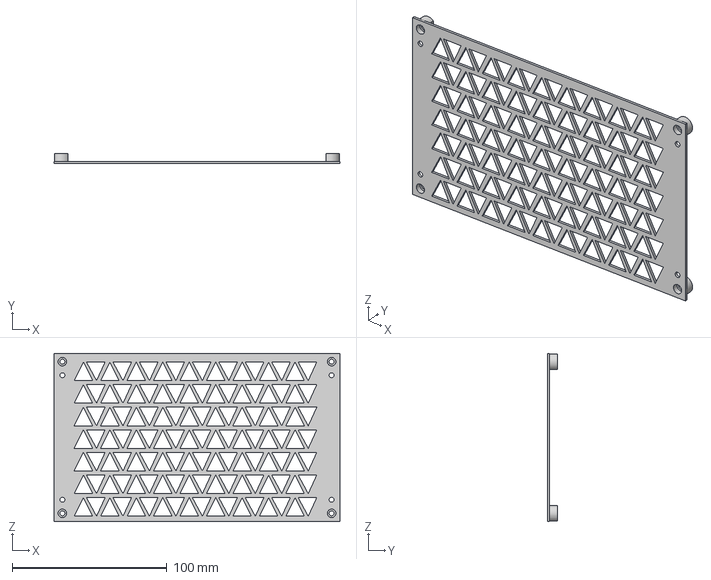
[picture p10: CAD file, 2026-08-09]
stl for printing/WEM Enclosure Back v7.step
184.8 x 6.60 x 108.8 mm

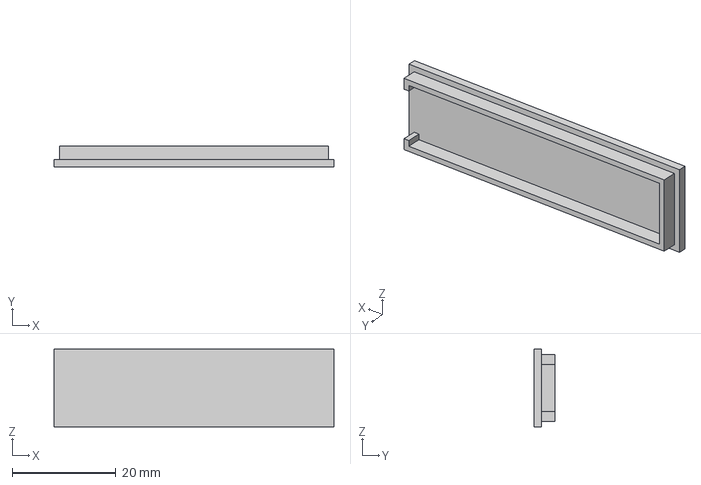
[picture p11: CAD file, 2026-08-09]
stl for printing/LD2410B_Mount_Top_v3.step
54.0 x 4.00 x 15.0 mm

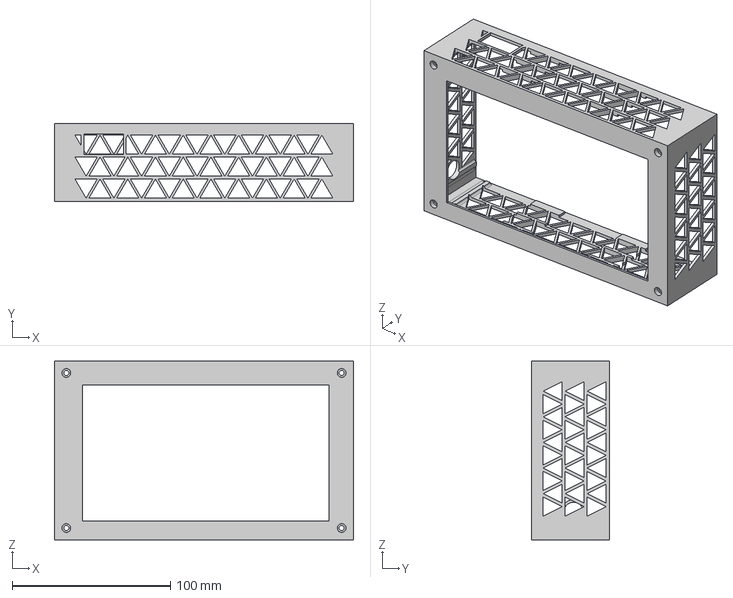
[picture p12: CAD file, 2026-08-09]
stl for printing/WEM Enclosure Body v17.step
189.0 x 49.0 x 113.0 mm

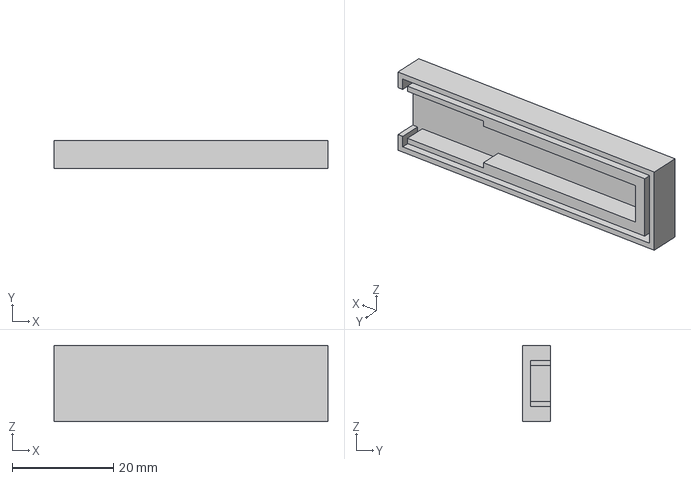
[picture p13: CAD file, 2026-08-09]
stl for printing/LD2410B_Mount_Body_v3.step
54.0 x 5.60 x 15.0 mm

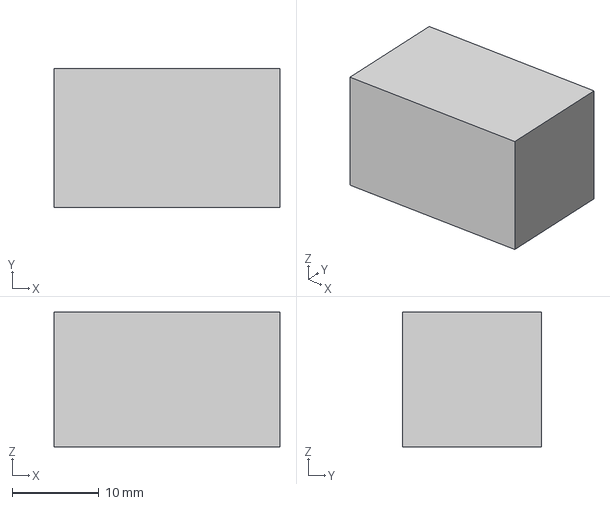
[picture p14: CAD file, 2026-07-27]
stl for printing/Buzzer Mount v1.step
26.0 x 16.0 x 15.5 mm

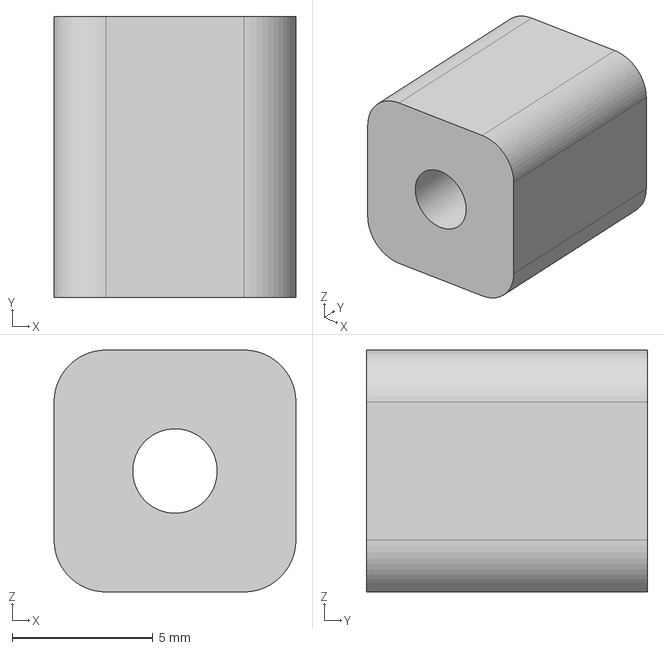
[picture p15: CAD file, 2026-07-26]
stl for printing/WEM Foot v2.step
8.60 x 10.0 x 8.60 mm

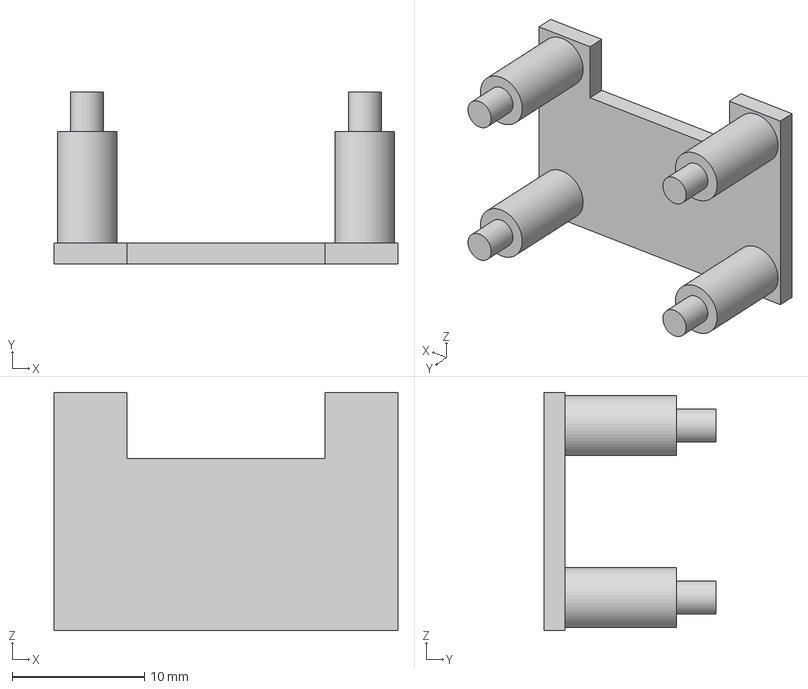
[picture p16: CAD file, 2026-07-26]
stl for printing/SGP30 SHT40 Mount v2.step
26.0 x 13.0 x 18.0 mm

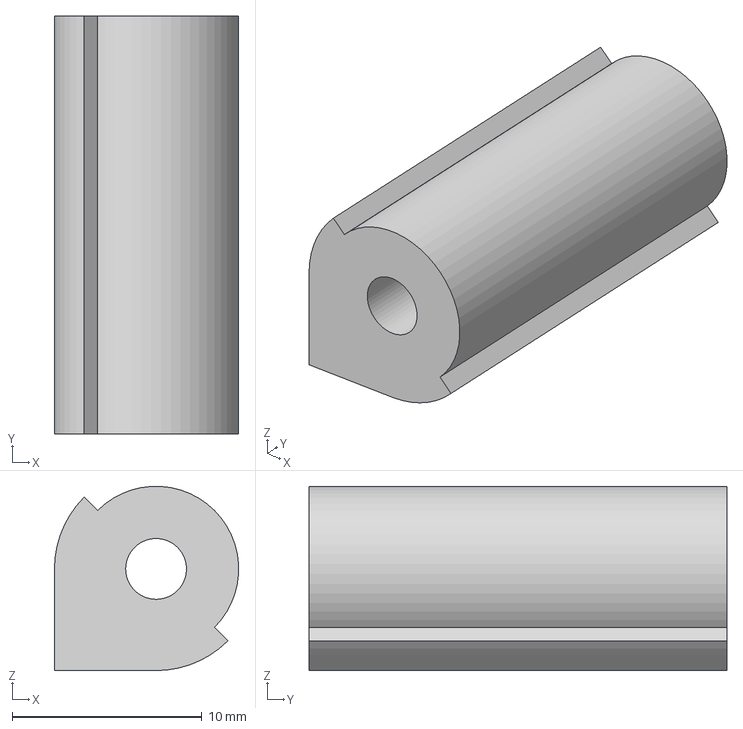
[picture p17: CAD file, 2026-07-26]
stl for printing/WEM PCB Fixing v6.step
9.69 x 22.0 x 9.69 mm

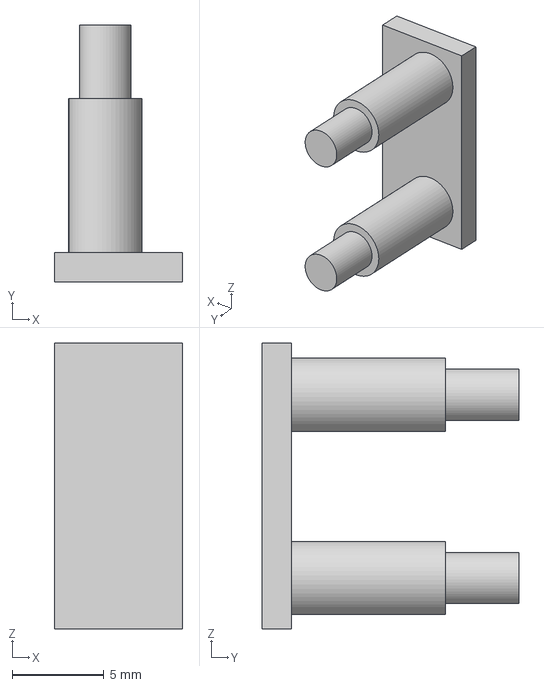
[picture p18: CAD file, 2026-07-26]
stl for printing/BME280 Mount v2.step
7.00 x 14.0 x 15.6 mm

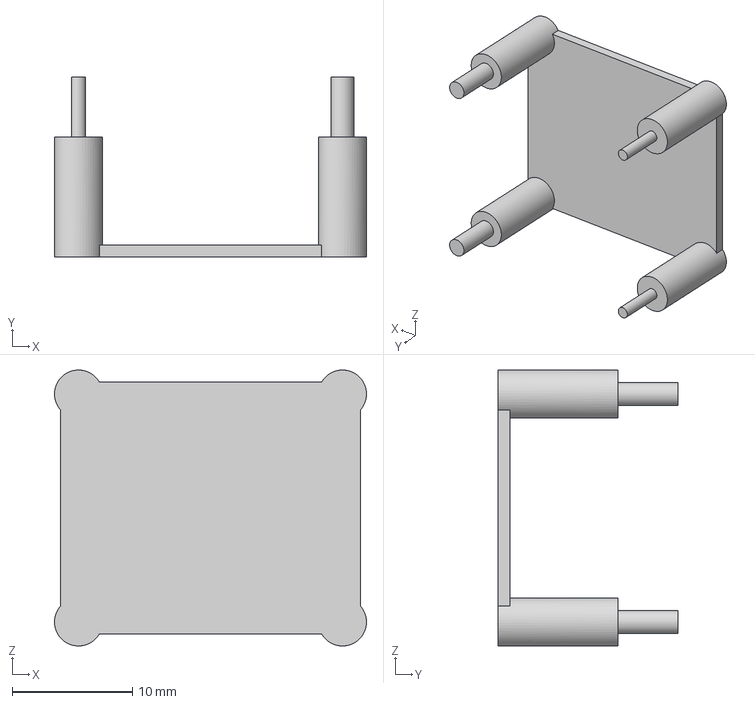
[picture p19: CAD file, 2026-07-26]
stl for printing/SFA40 Mount v6.step
26.0 x 15.0 x 23.0 mm

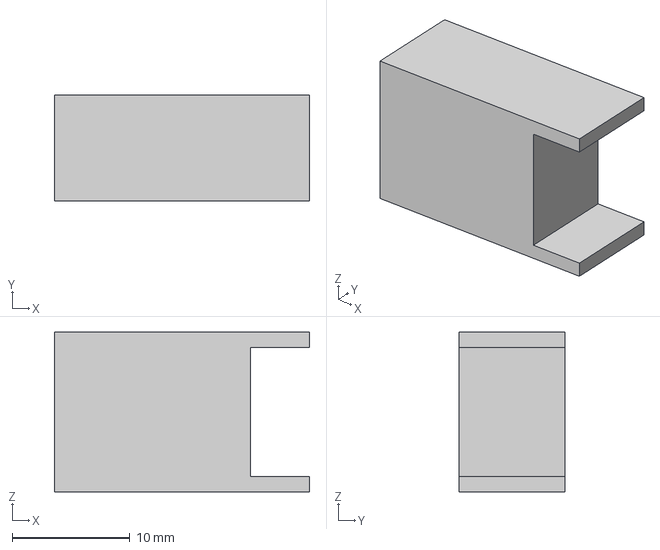
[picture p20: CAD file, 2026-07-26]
stl for printing/SCD40 Mount v2.step
21.7 x 9.00 x 13.6 mm

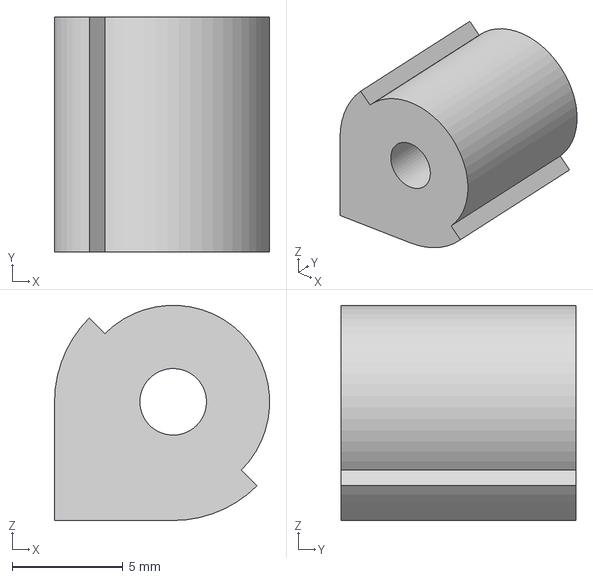
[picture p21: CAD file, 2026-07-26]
stl for printing/WEM Display Fixing v8.step
9.69 x 10.6 x 9.69 mm

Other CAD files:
stl for printing/LD2410B Mount v3.f3d

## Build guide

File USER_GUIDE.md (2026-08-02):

SPDX-License-Identifier: CC-BY-SA-4.0
SPDX-FileCopyrightText: 2026 Kevin Guest (BionicBone)

# Workshop Environment Monitor — User Guide

**Project home:** <https://github.com/bionicbone/Workshop-Environment-Monitor>

This guide covers getting a fresh WEM running and keeping it that way:
compiling and flashing the firmware, first boot, day-to-day touchscreen
controls, what the hardware looks like under the hood, and what to do when
something looks wrong. For licensing, third-party attribution, and repository
structure, see `README.md` in the repository root (link above).

This document describes WEM as built at **v1.0.0**, and covers the device as
it is — not how it came to be that way. The development history isn't
published.

---

## 1. Building, Flashing and First Boot

### 1.1 Building and flashing the firmware

v1.0.0 is a **compile-it-yourself release** — there's no pre-built binary to
download. A compiled WEM image has your WiFi and MQTT credentials baked into
it, so a shared binary would either leak them or be useless to anyone else.
You build it yourself against your own `secrets.h`. (A way to enter
credentials on the device at first boot is planned as a fast-follow; once that
exists, pre-built binaries can be published too.)

**What you need**

- The **Arduino IDE** (1.8.x or 2.x). WEM is developed in Visual Studio with
  the Visual Micro extension, but it builds unmodified in the standard Arduino
  IDE, and the settings below map directly onto the Arduino IDE **Tools** menu.
- The **ESP32 Arduino core** ("esp32" by Espressif Systems), installed through
  **Boards Manager**. WEM is tested on core **v2.0.17** and **v3.3.10** —
  either works. On any other version the firmware still runs, but the boot log
  prints a "core version has not been tested" line.
- The repository contents: the sketch folder, `secrets.h.example`, and the
  `Libraries/` folder.

**Step 1 — use the vendored libraries (don't skip this).** The repository's
`Libraries/` folder holds the exact copies of every library WEM was built and
tested against. **Use these rather than installing from the Library Manager.**
Copy each folder from `Libraries/` into your Arduino sketchbook `libraries/`
directory (usually `Documents/Arduino/libraries/`), replacing any existing
copy of the same name, then restart the IDE.

This matters most for **TFT_eSPI**, which is pre-configured for WEM's exact
800×480 SSD1963 panel. The firmware checks this at compile time and stops with

```
#error "Incorrect TFT_eSPI Display Setup - should be 50"
```

if it's built against a stock TFT_eSPI. The vendored copy is already set to
display setup 50, so with it this never fires.

**Step 2 — create your `secrets.h`.** Copy `secrets.h.example` to `secrets.h`
in the sketch folder and fill in your WiFi SSID and password, and your MQTT
broker address, port and credentials. `secrets.h` is git-ignored and must
never be committed — it's the one file holding your credentials, and keeping
it out of version control is what makes the compile-it-yourself model safe.

**Step 3 — select the board and settings.** Set **Board** to **ESP32S3 Dev
Module**, then match every option below. These are the exact settings WEM is
built and tested with.

| Setting | Value |
|---|---|
| Upload Speed | 921600 |
| USB Mode | Hardware CDC and JTAG |
| USB CDC On Boot | Enabled |
| USB Firmware MSC On Boot | Disabled |
| USB DFU On Boot | Disabled |
| Upload Mode | UART0 / Hardware CDC |
| CPU Frequency | 240MHz (WiFi) |
| Flash Mode | QIO 80MHz |
| Flash Size | 16MB (128Mb) |
| Partition Scheme | 16M Flash (3MB APP/9.9MB FATFS) |
| Core Debug Level | None |
| PSRAM | **Disabled** |
| Arduino Runs On | Core 1 |
| Events Run On | Core 1 |
| Erase All Flash Before Sketch Upload | Disabled |
| JTAG Adapter | Disabled |

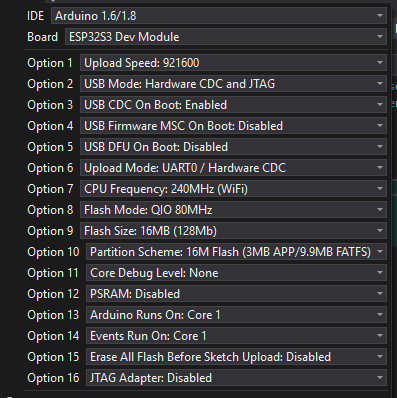
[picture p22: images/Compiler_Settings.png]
WEM board settings for the ESP32S3 Dev Module


Two of these are not optional:

- **PSRAM must be Disabled.** WEM uses GPIO35 and GPIO36, which on this module
  sit on the octal-PSRAM bus (see the pin map in 4.5). Enabling PSRAM takes
  those pins over and the build won't work correctly.
- **Flash Size 16MB with the 16M (3MB APP / 9.9MB FATFS) partition.** The
  firmware is built to this layout; a smaller flash size or a different
  partition scheme can fail to upload or leave no room for the FATFS area.

**USB CDC On Boot: Enabled** is why the serial monitor works over the same
USB-C cable you flash with — no separate USB-serial adapter needed.

**Step 4 — compile and upload.** Connect the board over USB-C, select its port
under **Tools → Port**, and click **Upload**. If the board isn't detected or
the upload won't start, hold the **BOOT** button, tap **RESET** (or re-plug the
cable), release **BOOT**, and try again — some ESP32-S3 boards need this to
enter the bootloader for a first flash.

**Step 5 — confirm it's running.** Open the **Serial Monitor at 115200 baud**.
You should see the boot banner:

```
Name        : Workshop Environment Monitor
Program     : v1.0.0
License     : AGPL-3.0-or-later, NO WARRANTY
Source      : https://github.com/bionicbone/Workshop-Environment-Monitor
```

followed by the Arduino core version and a line for each sensor as it's probed
(for example `SHT40: Found and initialised`, or `SHT40: Sensor not found at
0x44!` for anything not fitted). A display-fitted unit also logs the touch
controller at `0x38`. "This ESP32 Arduino Core version has not been tested"
just means you're not on v2.0.17 or v3.3.10 — the firmware still runs.

> **Getting diagnostic logs.** The release build ships with `DEBUG 0` in
> `Global.h`, so normal operation is quiet apart from the boot banner. If
> you're chasing a problem or filing an issue, set `DEBUG 1`, re-flash, and
> capture the serial output — that detailed log is the thing worth attaching
> to a bug report.

### 1.2 Before you power on

By this point you've built and flashed the firmware (1.1), so `secrets.h` is
already in place. Before the first power-up:

- Confirm every sensor you intend to fit is connected — WEM auto-detects
  what's present at boot (see [Optional Sensors](#5-optional-sensors)), so a
  loose connector just means that sensor sits out, not a crash.
- If you're powering from the 19V mains PSU, double-check polarity at the
  barrel connector before first power-up.

### 1.3 What happens on first boot

1. WEM checks whether a display is fitted. If one is, it initialises and
   shows a splash screen — project name, version, source link, licence and
   a short disclaimer — which stays up for the rest of boot. If not, WEM
   runs headless and publishes to Home Assistant only — see
   [Running Without a Display](#6-running-without-a-display-headless).
2. WEM attempts to connect to WiFi (a few retries, then continues in a
   degraded/offline state rather than hanging — it'll pick the connection up
   automatically later if it appears). On a display-fitted unit, a "WiFi"
   line is added to the splash screen once this finishes, showing whether it
   connected.
3. If WiFi connects, MQTT and Home Assistant discovery follow, along with
   NTP time sync and OTA readiness.
4. Each sensor is probed, with up to 3 seconds of retries before WEM gives up
   on it — a slow-to-wake sensor gets a fair chance rather than being written
   off on one failed attempt. Anything that still doesn't answer is marked
   absent for the rest of the session: its gauge/row greys out permanently
   rather than freezing on stale data. No firmware changes are needed to run
   with a subset of sensors. Expect boot to take noticeably longer when
   sensors are missing — that's the retry windows elapsing, not a fault. On a
   display-fitted unit, each sensor is added to the splash screen's list as
   it's probed, so a long boot is visibly progressing rather than looking
   frozen. **The HCHO sensor (SFA40) doesn't appear in this list** — it's a
   passive UART stream with no boot-time check to report, so there's nothing
   to show yet at this point; see [Optional Sensors](#5-optional-sensors).
5. **The SGP30 (TVOC) sensor starts a warm-up period** before it publishes
   real numbers — 12 hours on a genuinely fresh start, or 1 hour if a
   previously-saved baseline was restored from flash. This is normal and
   expected of the sensor itself, not a fault.
6. Once every step above has finished, a display-fitted unit holds the
   completed splash screen briefly, then switches to the normal dashboard.
   From here on the display behaves as described in
   [section 2](#2-touchscreen-controls) onward.

### 1.4 First boot in a new or freshly-printed enclosure

If your WEM enclosure was just 3D printed, or you've just finished soldering
nearby, don't let the SGP30 form its first calibration baseline while
sitting in that off-gassing air — it will bake the fumes into its reference
point and under-report real contamination afterwards. This is the single
most important thing to get right on a first build, and it only takes a few
minutes of thought before you power on.

**Step 1 — ask yourself: was this build near fresh off-gassing sources?**
This includes a freshly-printed enclosure (ABS/PETG/PLA all off-gas for a
while after printing, ABS particularly), solder fumes from assembling the
PCB, or strong VOCs nearby (paint, solvent, adhesives, new foam packaging)
in the hours before first power-up.

- **No, none of that applies** (an already-aired-out enclosure, board
  assembled a while ago, normal workshop air) → power on and let the
  standard 12h warm-up gate run as-is. Nothing further needed — skip to
  [section 2](#2-touchscreen-controls).
- **Yes, or you're not sure** → follow the procedure below.

**Step 2 — the recommended procedure:**

1. **Power on and let the enclosure/board air out somewhere well
   ventilated first** — outdoors or by an open window, for a few hours if
   possible. The display and other sensors work normally during this time;
   only the SGP30's calibration is at risk.
2. **Then start the 12h warm-up "for real"** once the air around the unit
   is back to normal. You don't need to do anything to "start" it — just
   make sure the SGP30 forms its baseline breathing normal air, not fresh
   off-gassing.
3. **If you skipped step 1** — you powered on directly in a contaminated
   environment, or you're unsure whether the warm-up window already
   overlapped with off-gassing — **clear the SGP30 baseline** (see
   [section 3](#3-clearing-the-sgp30-baseline-nvs-reset)) once the air has
   settled. This discards whatever baseline was forming and restarts a
   clean 12h window. It's quick (a 5-second touch long-press) and doesn't
   touch your WiFi/MQTT configuration.

**This only affects the SGP30 (TVOC/eCO2).** The other sensors don't hold a
calibration baseline and need no special first-boot handling — CO2, HCHO,
temperature, humidity, and particulates all read normally from the first
boot regardless of the environment.

When genuinely unsure which path applies, **step 3 (clear the baseline) is
always the safe default** — there's no harm in clearing a baseline that
didn't need clearing, but there's no way to un-bake a contaminated one
short of clearing it.

---

## 2. Touchscreen Controls

> These controls need a display fitted — the touch sensor lives on the
> display's own ribbon. If you're running headless, see
> [Running Without a Display](#6-running-without-a-display-headless) for what
> you lose and what to do instead.

| Action | Effect |
|---|---|
| Short tap | Wakes the display from backlight sleep, or snoozes an active alarm |
| Hold for 5 seconds | Clears the stored SGP30 baseline and reboots (see below) |

The long-press is confirmed by a distinct tone (four short beeps + one long
beep) — different from the two-beep alarm pattern, so you can tell them
apart without looking at the screen. The unit then reboots automatically
once the tone finishes **and** your finger has lifted off the screen.

---

## 3. Clearing the SGP30 Baseline (NVS Reset)

### Why you'd want to do this

The SGP30 saves its calibration baseline to flash (NVS) roughly once an
hour, and restores it on every boot so it doesn't have to fully recalibrate
after a normal power cycle. That saved baseline is tied to the **physical
chip** it came from. You should clear it whenever:

- **You've replaced the physical SGP30** — restoring an old chip's baseline
  onto a new one produces plausible-looking but wrong readings (commonly
  seen as TVOC/eCO2 reading flat or stuck). Clear it *before* trusting the
  new sensor, not after you've noticed bad data.
- **First boot happened in a contaminated environment** (see 1.4 above).
- Readings look implausibly flat or pinned and you suspect a bad baseline.

### How to clear it

**Recommended — long-press the touchscreen for 5 seconds.** Hold until you
hear the confirmation tone (four short beeps, one long beep), then release.
The unit reboots automatically and starts a fresh calibration window. This
is quick, doesn't touch your WiFi/MQTT settings, and is the only method most
users will ever need.

**Fallback — full flash erase.** Only necessary if the long-press mechanism
itself is unavailable — which currently includes every headless build (see
[Running Without a Display](#6-running-without-a-display-headless)), as well
as a display fault. This wipes *everything* in flash, including your WiFi and
MQTT credentials — you'll need to reconfigure `secrets.h` and reflash
afterwards.

> If you're running headless and this looks like a lot of ceremony just to
> reset one sensor — agreed. A Home Assistant button for this is the next
> thing on the list after release.

---

## 4. Hardware Reference

### 4.1 Sensor summary

| Sensor | Measures | Interface | Voltage | Read cadence | HA publish rate |
|---|---|---|---|---|---|
| SGP30 | TVOC / eCO2 | I2C (0x58) | 3.3V | Every 1s (sensor requirement) | ~every 30s |
| SFA40 | HCHO (formaldehyde) | UART | 5V | Every loop (UART-driven) | ~every 30s |
| SCD40 | CO2 | I2C (0x62) | 5V | Every 5s | ~every 30s |
| SHT40 | Temperature / humidity (primary, drives the display) | I2C (0x44) | 5V | Every 5s | ~every 30s |
| BME280 | Temperature / humidity (secondary, HA-only) | I2C (0x76) | 3.3V | Every 5s | ~every 30s |
| PMS5003 | Particulates — 6 count channels + 3 mass concentrations (see 4.2) | UART | 5V | 120s duty cycle (25% on-time) | ~every 120s |
| LD2410B | mmWave presence (optional) | UART | 5V (3.3V logic) | Continuous | — (local use only) |
| FT5x06 | Capacitive touch | I2C (0x38) | 3.3V | Continuous | — |

The FT5x06 does double duty: WEM also uses its presence on the I2C bus to work
out whether a display is fitted at all. See
[Running Without a Display](#6-running-without-a-display-headless).

**The 7" TFT display panel itself runs on 5V** (with 3.3V logic and a 3.3V
backlight-enable input). Only the FT5x06 touch controller listed above is a
3.3V part — the panel is not. This matters when ordering: these 7" 800x480
modules are commonly sold in both 3.3V and 5V variants, and WEM is built for
the **5V** version. Order the 5V variant — the 3.3V one is not a drop-in
substitute on this board.

Sensor reads happen at the cadence each sensor's own hardware needs; Home
Assistant publishing is decoupled from that and rate-limited separately, so
HA doesn't get flooded with near-duplicate values.

A sensor that isn't fitted is simply skipped — no reads attempted, no
gauge/entity populated, no crash. See [Optional Sensors](#5-optional-sensors).

### 4.2 Particulate channels — counts vs mass

The PMS5003 reports particulates two different ways, and WEM publishes both.
They are not interchangeable and the distinction matters:

| Channel | Unit | What it is |
|---|---|---|
| PM0.3 / PM0.5 / PM1.0 / PM2.5 / PM5.0 / PM10 **Count** | cnt/0.1L | How *many* particles of at least that size were counted in a 0.1 litre sample |
| PM1.0 / PM2.5 / PM10 **Atmospheric** | ug/m3 | Estimated *mass* of particulate matter suspended per cubic metre |

All nine appear on the display's left-hand panel and as separate Home
Assistant entities.

**Why the small counts matter.** PM0.3 and PM0.5 are the channels worth
watching for 3D printing. Ultrafine particles emitted while printing are
numerous but individually almost weightless, so they can be present in very
large numbers while the mass figures still read near zero — a monitor that
only reported ug/m3 would tell you the air was fine. The count channels are
there so it doesn't.

> **Alarms use the mass figures only** — PM2.5 and PM10 in ug/m3, never the
> counts. The count channels are informational: there's no widely-agreed
> health threshold to alarm against, and a raw particle count varies far too
> much with normal workshop activity to make a sensible trigger. See
> [Alarms and Thresholds](#7-alarms-and-thresholds).

### 4.3 I2C bus (Wire1 — SDA on GPIO1, SCL on GPIO4)

| Address | Device | Sensor |
|---|---|---|
| 0x38 | FT5x06 | Capacitive touch |
| 0x44 | SHT40 | Temperature / humidity |
| 0x58 | SGP30 | TVOC / eCO2 |
| 0x62 | SCD40 | CO2 / temp / humidity |
| 0x76 | BME280 | Temp / humidity / pressure |

### 4.4 UART connections

| Interface | Device | Baud |
|---|---|---|
| Serial0 | LD2410B (mmWave presence) | 256000 |
| Serial1 | SFA40 (HCHO) | 9600 |
| Serial2 | PMS5003 (particulates) | 9600 |

### 4.5 GPIO pin map (ESP32-S3)

| GPIO | Function | Notes |
|---|---|---|
| 1 | I2C1 SDA | Shared sensor bus (Wire1) |
| 2 | Touch interrupt | FT5x06 |
| 3 | TFT write strobe | Parallel display interface |
| 4 | I2C1 SCL | Shared sensor bus (Wire1) |
| 5–8, 15–18 | TFT data bus (D0–D7) | 8-bit parallel display interface |
| 10 | Backlight control | HIGH = on, LOW = off |
| 21 | PMS5003 RX (Serial2) | Particulate sensor |
| 35 | PMS5003 TX (Serial2) | Particulate sensor |
| 36 | Oscilloscope test point | Debug only — not required for normal use |
| 38 | SFA40 TX (Serial1) | HCHO sensor |
| 39 | LD2410B RX (Serial0) | Presence sensor |
| 40 | LD2410B TX (Serial0) | Presence sensor |
| 41 | LD2410B presence output | Direct digital read |
| 42 | SFA40 RX (Serial1) | HCHO sensor |
| 47 | Buzzer PWM | Drives alert piezo via transistor |
| 48 | TFT D/C | Data/command select |

GPIO 19, 20 (USB), 33–34 (PSRAM traces), 43, 44 (USB serial) are reserved by
the board itself — don't repurpose them if you're modifying the PCB. GPIO
35–37 sit on PSRAM traces too, but PSRAM is disabled in this build's compiler
settings, which frees them — hence 35 and 36 appearing in the table above.
GPIO 9, 11, 12, 13 and 14 are genuinely unallocated if you need a spare.

### 4.6 Power

| Rail | Source |
|---|---|
| 19V | External mains PSU (barrel connector) |
| 5V | On-board switching regulator, from 19V |
| 3.3V | ESP32-S3 dev board's own regulator, from 5V |

WEM can also run from USB power alone (5V) for bench testing, but the 19V
input is recommended for permanent installs.

---

## 5. Optional Sensors

Every sensor in the table above is optional. WEM probes each one at boot,
retrying for up to 3 seconds before giving up; anything not fitted (or not
responding) is marked absent for that session and cleanly excluded from:

- the display (its gauge/row greys out rather than showing stale data),
- Home Assistant (no entity ever gets pushed for a sensor that never
  answered),
- alarm logic (an absent sensor can never trigger a false alarm).

This means you can build a cut-down WEM with only the sensors that matter to
you — no firmware changes required either way.

**The display is optional on the same terms**, with one difference worth
knowing about: leaving it off costs you the alarm snooze and the SGP30
baseline reset, because both are triggered by touch. See
[Running Without a Display](#6-running-without-a-display-headless).

---

## 6. Running Without a Display (Headless)

The 7" touchscreen is optional, just like the sensors. Leave it off and WEM
runs headless: every sensor is read as normal and everything is published to
Home Assistant exactly as it would be otherwise. If you already live in the HA
dashboard, or you're mounting WEM somewhere nobody will look at it, this is a
perfectly sensible way to build one — and it's cheaper.

No firmware changes or build flags are needed. Just don't connect the display.

### 6.1 How WEM knows

WEM looks for the touch controller on the I2C bus at boot. Found means a
display is fitted; not found means headless. You'll see one of these in the
serial log:

```
TFT: Touch controller found at 0x38 - display fitted
```

```
TFT: Touch controller not found at 0x38 - display assumed NOT fitted
TFT: Running WITHOUT display (Home Assistant only).
```

This check runs once, at boot. **Connecting a display to a running WEM won't
do anything until you restart it.**

**One thing to watch:** the display panel itself can't be detected directly —
there's no electrical path to ask it whether it's there. WEM asks the touch
controller instead, which shares the display's ribbon cable. So if the touch
ribbon isn't fully seated, WEM will decide there's no display and leave the
screen dark, even though the panel is physically connected. **If you've fitted
a display and the screen stays black, reseat the touch ribbon first** — it's
by far the most likely cause.

### 6.2 What you give up

Everything you lose comes from the same root: no display means no touchscreen,
and touch is currently WEM's only input.

| | Headless |
|---|---|
| Sensor readings | Full — unchanged |
| Home Assistant / MQTT | Full — unchanged |
| OTA firmware updates | Full — unchanged |
| Audible alarm | Sounds normally — **but cannot be silenced** |
| Alarm snooze | Not available |
| SGP30 baseline reset | Not available (flash erase only) |
| On-screen gauges, backlight | Not applicable |

Two of those deserve spelling out.

**The alarm can't be snoozed.** It will sound its two-beep pattern every few
seconds for as long as the reading stays over threshold. There's no way to
silence it from the device. This bites hardest if you also skipped the LD2410B
presence sensor, because then the alarm isn't gated on someone being in the
room either — it'll sound whether you're there or not. Two practical options
in the meantime: fit an LD2410B (cheap, and it gates the alarm on presence),
or fix the underlying air quality, which is admittedly the point of the device.

**The SGP30 baseline can't be cleared.** The 5-second long-press described in
[section 3](#3-clearing-the-sgp30-baseline-nvs-reset) needs a touchscreen. On
a headless unit your only route is a full flash erase and reflash. This mainly
matters if you ever swap the physical SGP30 chip — see section 3 for why that
requires a baseline clear.

> **Both of these are known v1.0.0 limitations, not permanent design.**
> Exposing snooze and baseline reset as Home Assistant buttons is the first
> thing planned after release — it needs no touchscreen and will work on every
> build, headless or not. If headless operation matters to you, it's worth
> watching <https://github.com/bionicbone/Workshop-Environment-Monitor> for that update.

---

## 7. Alarms and Thresholds

WEM raises an audible alarm (piezo buzzer) and a visual warning on the
display when a reading crosses its threshold. Thresholds are chosen to flag
"you should probably act on this now", not raw sensor limits:

| Reading | Alarm threshold | Basis |
|---|---|---|
| CO2 | > 2000 ppm | Ventilation/comfort proxy, not toxicity; well under the 5000 ppm workplace 8-hour limit |
| TVOC | > 660 ppb | TVOC has no health-based limit — it's a relative indicator; 660 ppb is the moderate-to-poor boundary on the common IAQ scale |
| HCHO (formaldehyde) | > 80 ppb | WHO residential guideline (~0.1 mg/m3 over 30 min); the workplace limit is roughly nine times higher |
| PM2.5 (mass) | > 35 ug/m3 | US EPA onset of "unhealthy for sensitive groups"; mass channel, not the particle count |
| PM10 (mass) | > 154 ug/m3 | Top of the US EPA "moderate" band; mass channel, not the particle count |

**WEM alarms early, on purpose.** These thresholds follow *residential*
air-quality guidance — the levels considered acceptable for the general
population, including children, the elderly and people with respiratory
conditions, breathing the air continuously. They are deliberately **not**
occupational limits. Workplace limits (OSHA/NIOSH) assume a healthy adult
exposed for an eight-hour shift and are far higher — the formaldehyde
workplace limit, for instance, is around nine times WEM's 80 ppb alarm. WEM is
built for a home workshop, where you may be present in the evenings and at
weekends and where the air is often shared with the rest of the house, so it
uses the stricter home numbers and errs toward warning you sooner.

All five sound the same two-beep pattern — the buzzer tells you *something* is
over threshold, not which. The display's left-hand status panel shows which
reading tripped.

**Particle counts never alarm.** Only the PM2.5 and PM10 mass figures do. See
[Particulate channels](#42-particulate-channels--counts-vs-mass) for why.

**Alarms don't switch off the instant a reading drops.** Two deliberate
behaviours stop a value hovering near its threshold from producing rapid
on/off flapping:

- Each hazard latches on at its threshold and only clears once the reading
  falls to **90% of it** (so CO2 alarms at 2000 ppm and clears below 1800).
- Once triggered, the alarm holds for **at least one full 3-second cycle**,
  even if the reading drops immediately.

If an alarm seems to linger slightly after the number looks fine, that's this
working as intended, not a stuck buzzer.

On a display-equipped unit, a tap on the screen snoozes an active alarm for 15
minutes. On a headless unit there's no way to silence it — see
[Running Without a Display](#6-running-without-a-display-headless).

A sensor that's gone stale (hasn't reported recently) is excluded from alarm
logic entirely — WEM won't sound an alarm based on old data, and won't stay
silent forever on a genuinely dead sensor either, since the display shows
that reading as greyed-out/stale so you can see something's wrong at a
glance.

### 7.1 Changing a threshold for your own use case

Every threshold lives as a `THRESH_` define in `Graphics.h` — for example
`THRESH_HCHO_WARN`. Each reading has two: a `GOOD` value (the green ceiling on
the display) and a `WARN` value (the orange/red boundary *and* the point the
buzzer uses). Raising `WARN` makes WEM alarm later; lowering it makes WEM alarm
sooner. After editing, recompile and reflash — see
[Building and flashing the firmware](#11-building-and-flashing-the-firmware).

There are legitimate reasons to raise one. A workshop lined with MDF, for
instance, will sit above the residential HCHO guideline much of the time purely
from off-gassing, and you may reasonably decide a higher alarm point matches
how you actually work. That's a fair call to make. But be clear about the
trade: raising a threshold means WEM stays silent while a reading sits in a
range that genuinely is unhealthy for continuous exposure. You're exchanging
early warning for fewer interruptions, and it's worth knowing that's the
exchange you've made.

Two things worth doing before you touch a number:

- **Find the root cause first.** An alarm that keeps firing is usually telling
  you something true. Ventilate, run a filter, move or enclose the source —
  fix the air, and the alarm often stops on its own with the threshold left
  alone. Raising the number to quieten a real problem doesn't fix anything; it
  just removes the warning while the problem carries on.
- **Don't set it somewhere it can never fire.** A threshold parked far above
  anything you'll realistically see is the same as switching that alarm off. If
  you raise it, raise it to a considered number — not to "never".

> **You own that decision.** WEM ships with conservative, health-forward
> defaults. Change them and the responsibility for what the device does and
> doesn't warn you about becomes yours. WEM is a hobby air-quality monitor, not
> a certified gas detector or life-safety product — as stated in the licence
> and the `NOT A SAFETY DEVICE` notice in the firmware source. Treat its
> readings and alarms as useful information to act on, never as a guarantee of
> safety.

---

## 8. Troubleshooting

**A sensor's gauge is permanently grey.** That sensor wasn't detected at
boot — check its wiring and power, then restart the unit. Detection only runs
during startup, so WEM won't notice a reconnected sensor until it reboots.
Either a soft reset or a full power cycle will re-probe.

**TVOC/eCO2 reads flat or stuck at an implausible value.** Almost always a
mismatched SGP30 baseline — see [Clearing the SGP30 Baseline](#3-clearing-the-sgp30-baseline-nvs-reset).

**A display is connected but the screen stays dark.** WEM decides whether a
display is fitted by looking for the touch controller on the I2C bus, so an
unseated touch ribbon reads as "no display" and the screen never initialises.
Reseat the touch ribbon and power-cycle. The serial log tells you which way
WEM decided — look for `TFT: Touch controller ... at 0x38` near the top of the
boot output. See
[Running Without a Display](#6-running-without-a-display-headless).

**Touchscreen stops responding entirely.** Rare, and under active
monitoring. If it happens, a full power cycle (disconnect and reconnect
power) clears it — a reset button/pulse alone will not, since the touch
controller has its own separate reset circuit. If you see this, it'd help
the project to report it — please open an issue at
<https://github.com/bionicbone/Workshop-Environment-Monitor/issues>.

**Display readings look plausible but Home Assistant shows nothing for a
sensor.** Check that WiFi/MQTT actually connected (the header status icons
reflect this). A sensor that's detected locally but never reaches HA is
almost always a network/broker issue, not a sensor fault.

---

## 9. Licensing

WEM firmware is licensed under AGPL-3.0-or-later; hardware (PCB and
enclosure) under CERN-OHL-W-2.0. This document is licensed under
[CC BY-SA 4.0](https://creativecommons.org/licenses/by-sa/4.0/). See the
`README.md` and `THIRD_PARTY_LICENSES.md` in the repository root for full
detail — both are at <https://github.com/bionicbone/Workshop-Environment-Monitor>.

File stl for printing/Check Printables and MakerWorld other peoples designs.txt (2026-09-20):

For the latest a greatest designs from the community check out Marker World and Printables

MakerWorld: https://makerworld.com/en/models/3154719-workshop-environment-monitor-display-enclosure#profileId-3564199
Printables: https://www.printables.com/model/1804737-workshop-environment-monitor-display-enclosure

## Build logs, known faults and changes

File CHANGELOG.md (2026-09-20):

# Changelog

All notable changes to this project will be documented in this file.

The format is based on [Keep a Changelog](https://keepachangelog.com/en/1.1.0/),
and this project adheres to [Semantic Versioning](https://semver.org/spec/v2.0.0.html).

## [Unreleased]

## [1.1.0] - 2026-09-20

### Added

- SGP30 humidity compensation — the sensor's eCO2/TVOC readings are now
  corrected against live temperature/humidity data, rather than running on
  the chip's fixed internal default.
- Two new Home Assistant sensors, `SGP30_eCO2_Baseline` and
  `SGP30_TVOC_Baseline`, exposing the sensor's saved calibration baseline
  so it can be inspected and tracked over time.

### Fixed

- SGP30 baseline sensors in Home Assistant could continue showing stale,
  pre-reset values after clearing the sensor's calibration — a cleared
  baseline is now correctly reflected in Home Assistant.

## [1.0.0] - 2026-07-30

Initial public release.

### Added

- ESP32-S3 firmware for the Workshop Environment Monitor: a 7" TFT
  touchscreen dashboard with Home Assistant MQTT integration.
- Multi-sensor environmental monitoring — VOC/eCO2 (SGP30), CO2 (SCD40),
  HCHO (SFA40), particulates (PMS5003), temperature/humidity (SHT40
  primary, BME280 secondary), and mmWave presence (LD2410B).
- Every sensor is optional and independently detected at boot — an
  unfitted or unresponsive sensor is cleanly excluded from the display,
  Home Assistant, and alarm logic rather than showing stale or invalid
  data.
- Configurable alarm thresholds (residential defaults) with hysteresis,
  and touchscreen snooze.
- SGP30 baseline management — automatic save/restore with a two-tier
  warm-up, and a touchscreen long-press procedure for resetting the
  baseline (e.g. after replacing the sensor).
- Home Assistant long-term statistics support across all numeric
  entities.
- Backlight sleep with presence-based wake, to reduce display burn-in
  risk.
- Headless (no display fitted) operation supported.
- Full hardware design released alongside the firmware — PCB Gerbers,
  enclosure/sensor-mount STL files, and a bill of materials.

[Unreleased]: https://github.com/bionicbone/Workshop-Environment-Monitor/compare/v1.1.0...HEAD
[1.1.0]: https://github.com/bionicbone/Workshop-Environment-Monitor/releases/tag/v1.1.0
[1.0.0]: https://github.com/bionicbone/Workshop-Environment-Monitor/releases/tag/v1.0.0

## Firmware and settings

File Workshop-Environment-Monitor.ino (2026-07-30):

// SPDX-License-Identifier: AGPL-3.0-or-later
// SPDX-FileCopyrightText: 2026 Kevin Guest (BionicBone)

/**************************************************************************
 * Workshop Environment Monitor (WEM)
 * ------------------------------------------------------------------------
 * Open-source ESP32-S3 workshop air quality monitor - CO2, TVOC, HCHO,
 * particulates, temperature and humidity, published to Home Assistant
 * over MQTT.
 *
 * Project : Workshop Environment Monitor (WEM)
 * Author  : Kevin Guest (BionicBone)
 * Created : May 2026
 * Source  : https://github.com/bionicbone/Workshop-Environment-Monitor
 * License : AGPL-3.0-or-later, NO WARRANTY - see LICENSE in repo root
 *
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
 * WHY AGPL: this firmware links against ArduinoHA
 * (home-assistant-integration), which is licensed AGPL-3.0. Linking makes
 * the compiled firmware a single combined work, so the whole project is
 * released under the same terms. Anyone who receives a compiled binary is
 * entitled to the complete corresponding source - see the repository link
 * above.
 *
 * THIRD-PARTY LIBRARIES: this project builds against third-party libraries
 * distributed under BSD, MIT, Apache-2.0, LGPL-2.1 and AGPL-3.0 terms. Full
 * copyright notices and license texts are reproduced in
 * THIRD_PARTY_LICENSES.md in the repository root.
 *
 * NOT A SAFETY DEVICE: this is a hobby air-quality monitor. It is not a
 * certified gas detector, fire alarm or life-safety product, and must not
 * be relied upon as one. See the No-Warranty and Limitation of Liability
 * sections of the license above.
 *
 * Please keep this notice intact in copies, forks and redistributions -
 * the AGPL requires copyright and license notices to be preserved, and it
 * keeps this file's provenance attached to the code.
 **************************************************************************/

// Workshop Environment Monitor.ino

// ============================================================
//  SENSOR TIMING SUMMARY
//  SFA40  HCHO    : every loop()   UART-driven, must never be delayed
//  SGP30  TVOC    : every 1 second   Sensirion algorithm requires 1s ticks
//  SCD40  CO2     : every 5 seconds   matches sensor internal cycle
//  BME280 Temp etc: every 5 seconds   fast sensor, 5s is adequate
//  SHT40  Temp/Hum: every 5 seconds   primary display source
//                   I2C address 0x44, Wire1   no conflict with existing sensors
//  PMS5003 PM     : 2-minute sleep/wake cycle, owned by loopPMS5003()
//                   (PMS5003_Particles.cpp) - wake at 1.5 min (90s),
//                   read+sleep at 2 min (120s), 30s stabilisation gap
//                   handled by timer difference (non-blocking)
//  SGP30 baseline : saved to flash every 1 hour
// ============================================================

#include "NetworkCanary.h"
#include "TimeSync.h"
#include <Update.h>             // Leave in - solves VS compile issues
#include <WiFi.h>               // WiFi.status()/WL_CONNECTED - used directly for the splash WiFi line
#include "Buzzer.h"
#include "Global.h"
#include "Backlight.h"
#include "Graphics.h"
#include "PMS5003_Particles.h"
#include "SGP30_VOC.h"
#include "SCD40_CO2.h"
#include "BME280_TEMP_HUMIDITY.h"
#include "HA_OTA.h"
#include "SFA40_HCHO_Sensor.h"
#include "LD2410B_Presence.h"   // after Global.h - needs Arduino core types

// ============================================================
//  SHT40   primary display temperature/humidity source
//  I2C address 0x44, Wire1   no conflicts with other sensors.
//  Graphics.cpp reads temperature/humidity from SHT40 only, deliberately
//  no fallback to SCD40 or BME280   see Schematic Reference for the
//  "SHT40 display override" rationale.
// ============================================================
#include "SHT40_TEMP_HUMIDITY.h"

#include "TimeSync.h"


void setup() {
  pinMode(OSC_PIN, OUTPUT);

  Serial.begin(115200);
  debugLoop("Started...");
  debugSpecial("Started...");

  Serial.printf("\nName        : Workshop Environment Monitor\nCreated     : May 2026\nAuthor      : Kevin Guest (BionicBone)\n");
  Serial.printf("Program     : %s\n", TOP_MENU_PROGRAM_VERSION);
  Serial.printf("License     : AGPL-3.0-or-later, NO WARRANTY\n");
  Serial.printf("Source      : https://github.com/bionicbone/Workshop-Environment-Monitor\n");
  Serial.printf("ESP-IDF     : %s\n", esp_get_idf_version());
  Serial.printf("Arduino Core: v%d.%d.%d\n", ESP_ARDUINO_VERSION_MAJOR, ESP_ARDUINO_VERSION_MINOR, ESP_ARDUINO_VERSION_PATCH);

  // Tested cores: v2.0.17 and v3.3.10. LEDC API is version-gated in
  // Buzzer.cpp/Buzzer.h to compile+run on both - see Schematic Reference,
  // "Arduino IDE Compiler Settings" for the full tested-version record.
  bool coreTested = (ESP_ARDUINO_VERSION == ESP_ARDUINO_VERSION_VAL(2, 0, 17)) ||
    (ESP_ARDUINO_VERSION == ESP_ARDUINO_VERSION_VAL(3, 3, 10));
  if (!coreTested) {
    Serial.printf("\n\nThis ESP32 Arduino Core version has not been tested\n");
    Serial.printf("Tested versions: v2.0.17, v3.3.10 - see Schematic Reference for detail\n");
    Serial.printf("***!!!*** PROCEED WITH CAUTION ***!!!***\n");
  }

  // ---- I2C first: the display is optional and detected over Wire1 ----
  // setupTFT() probes the FT5x06 touch controller at 0x38 to decide whether
  // a display is fitted at all (see "OPTIONAL DISPLAY GATE" in Graphics.h),
  // so the bus MUST be up before it is called. This is why Wire1.begin() and
  // the bus scan now run first - setupTFT() used to be the very first call
  // in setup().
  bool wire1Init = Wire1.begin(I2C1_SDA, I2C1_SCL, 100000);
  if (!wire1Init) {
    Serial.println("Failed to initialize Wire1 (Bus 1)");
  }

  scanI2CBus(Wire1, "Wire1 (Bus 1)");
  // Expected devices:
  // 0x38 - TFT Capacitive Touch  (absent = no display fitted, see setupTFT())
  // 0x44 - SHT40
  // 0x58 - SGP30
  // 0x62 - SCD40
  // 0x76 - BME280

  // Ordering below is fixed and load-bearing:
  //   setupTFT()       latches displayDetected - must run before the two
  //                    calls that gate on it.
  //   setupBacklight() gates on displayDetected.
  //   setupBuzzer()    must follow setupTFT() because TFT_eSPI initialises
  //                    LEDC internally - see the "LEDC API" note in Buzzer.h
  //                    for what changes when no display is fitted.
  setupTFT();
  setupBacklight();
  setupBuzzer();
  setupLD2410B();
  splashLine("LD2410B Presence", ld2410Detected);

  setupWifi();
  splashLine("WiFi", WiFi.status() == WL_CONNECTED);
  setupTimeSync();          // start NTP sync ASAP - async, doesn't block on WiFi
  setupOTA();

  // Set up all sensors BEFORE setting up Home Assistant MQTT
  // SFA40 has no detection gate (passive UART, no probe possible - see
  // Schematic Reference) and deliberately has no splash line for the same
  // reason: there is nothing true to report yet at this point in setup().
  setupSFA40_HCHO();
  setupBME280();
  splashLine("BME280", bme280Detected);
  setupSCD40_CO2();
  splashLine("SCD40 CO2", scd40Detected);
  setupSGP30_VOC();
  splashLine("SGP30 VOC", sgp30Detected);
  restoreSGP30Baseline();   // Restore SGP30 calibration baseline from flash
  setupPMS5003();
  splashLine("PMS5003", pms5003Detected);

  // SHT40   primary display temperature/humidity (overwrites SCD40 display globals)
  setupSHT40();
  splashLine("SHT40", sht40Detected);

  // Leave at the very bottom
  setupHA();
  setupNetworkCanary();     // self-contained network-health probe - see NetworkCanary.h
  setupVentSubscription();

  // Splash screen hand-off: hold the completed progress list briefly so the
  // last line or two is actually readable, then switch to the normal
  // dashboard. No-op on a headless build (displayDetected false).
  if (displayDetected) {
    delay(SPLASH_HOLD_MS);
    drawStaticChrome();
  }

  debugLoop("Completed, running the main loop");
  debugSpecial("Completed, running the main loop");
}


void loop() {
  OSC_PIN_PULSE(1);
  // --- OTA: Listen for over-the-air updates ---
  ArduinoOTA.handle();

  // --- Backlight: schedule ---
  loopBacklight();

  // --- Buzzer for Warnings - Touch to silence for a preiod of time ---
  loopBuzzer();

  // --- LD2410B mmWave: presence detection ---
  loopLD2410B();

  // --- WiFi: actively monitor + recover connection (built-in auto-reconnect
  //     is not reliable after a genuine AP/router power-cycle) - must run
  //     before loopHA()/loopVentSubscription() so they see current status ---
  loopWifi();

  // --- MQTT: Keep connections alive   must run every loop ---
  loopHA();
  loopNetworkCanary();    // drives netHealthState PROBATION -> HEALTHY promotion - see NetworkCanary.h
  loopVentSubscription();
  loopTimeSync();         // periodic NTP vs MQTT cross-check (gated internally)

  // ---- SFA40 HCHO: UART-driven   must run every loop ----
  // Buffers incoming serial bytes; misses data if called on a timer
  updateSFA40_HCHO();

  unsigned long currentMillis = millis();

  // ---- SGP30 TVOC: 1-second timer ----
  // Sensirion requires IAQmeasure() called every 1 second for the
  // on-chip baseline compensation algorithm to function correctly.
  // Running less frequently degrades TVOC accuracy over time.
  static unsigned long lastSGP30Update = 0;
  if (currentMillis - lastSGP30Update >= 1000) {
    updateSGP30_VOC();
    lastSGP30Update = currentMillis;
  }

  // ---- 5-second sensors: SCD40, BME280, SHT40 ----
  static unsigned long lastSlowUpdate = 0;
  if (currentMillis - lastSlowUpdate >= 5000) {
    updateSCD40_CO2();
    updateBME280();
    updateSHT40();   // runs AFTER SCD40 so SHT40 values win for display globals
    lastSlowUpdate = currentMillis;
  }

  // ---- PMS5003: 120s sleep/wake cycle ----
  // Cycle timing now owned by PMS5003_Particles.cpp (loopPMS5003()) rather
  // than tracked here, matching loopBacklight()/loopLD2410B()/loopWifi()/
  // loopBuzzer() - see PMS5003_Particles.cpp for the full cycle timeline
  // and the wakePMS5003()-must-not-block note.
  loopPMS5003();

  // ---- Header: refresh every 60 seconds for WiFi status ----
  // The header also updates immediately when MQTT time arrives (via setDirtyHeader
  // in HA_OTA.cpp), so this is just a fallback for WiFi status changes.
  static unsigned long lastHeaderRefresh = 0;
  if (currentMillis - lastHeaderRefresh >= 60000UL) {
    setDirtyHeader();
    lastHeaderRefresh = currentMillis;
  }
  // Baseline is used on next boot to restore calibration immediately.
  static unsigned long lastBaselineSave = 0;
  if (currentMillis - lastBaselineSave >= 3600000UL) {
    lastBaselineSave = currentMillis;
    saveSGP30Baseline();
  }

  // ---- Display update: respects dirty flag and minimum interval ----
  updateDisplay();
}

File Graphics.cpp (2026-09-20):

// SPDX-License-Identifier: AGPL-3.0-or-later
// SPDX-FileCopyrightText: 2026 Kevin Guest (BionicBone)

/**************************************************************************
 * Workshop Environment Monitor (WEM)
 * ------------------------------------------------------------------------
 * Open-source ESP32-S3 workshop air quality monitor - CO2, TVOC, HCHO,
 * particulates, temperature and humidity, published to Home Assistant
 * over MQTT.
 *
 * Project : Workshop Environment Monitor (WEM)
 * Author  : Kevin Guest (BionicBone)
 * Created : May 2026
 * Source  : https://github.com/bionicbone/Workshop-Environment-Monitor
 * License : AGPL-3.0-or-later, NO WARRANTY - see LICENSE in repo root
 *
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
 * WHY AGPL: this firmware links against ArduinoHA
 * (home-assistant-integration), which is licensed AGPL-3.0. Linking makes
 * the compiled firmware a single combined work, so the whole project is
 * released under the same terms. Anyone who receives a compiled binary is
 * entitled to the complete corresponding source - see the repository link
 * above.
 *
 * THIRD-PARTY LIBRARIES: this project builds against third-party libraries
 * distributed under BSD, MIT, Apache-2.0, LGPL-2.1 and AGPL-3.0 terms. Full
 * copyright notices and license texts are reproduced in
 * THIRD_PARTY_LICENSES.md in the repository root.
 *
 * NOT A SAFETY DEVICE: this is a hobby air-quality monitor. It is not a
 * certified gas detector, fire alarm or life-safety product, and must not
 * be relied upon as one. See the No-Warranty and Limitation of Liability
 * sections of the license above.
 *
 * Please keep this notice intact in copies, forks and redistributions -
 * the AGPL requires copyright and license notices to be preserved, and it
 * keeps this file's provenance attached to the code.
 **************************************************************************/

// Graphics.cpp
// 
// Workshop Environment Monitor - Display Rendering
//
// LAYOUT:
//    Left panel:  status indicators (top) + PM bars (bottom)
//    Centre:      arc gauges
//    Right panel: Outside Ref block (top) + Vent block (bottom) + LD2410B
//                 presence block
//
// updateOutsideBlock():
//    Displays outdoor temperature and humidity from rtl_433 Nexus-TH via MQTT.
//    Stale detection: values rendered in COL_STALE if no update within
//    OUTSIDE_STALE_MS. Snapshot guard prevents unnecessary redraws (same
//    pattern as updateVentBlock()).
//
// PM BARS:
//    Geometry driven entirely from the PBAR_* defines in Graphics.h - no
//    hardcoded widths in this file.

#include "Graphics.h"
#include "LD2410B_Presence.h"   // ld2410Presence, ld2410MovingEnergy, ld2410StillEnergy, ld2410Distance
#include "TimeSync.h"           // timeSyncState - header sync warning
#include <WiFi.h>

// ============================================================
//  OPTIONAL DISPLAY GATE
//  Latched once by setupTFT(), read by updateDisplay() below, by
//  Backlight.cpp and by readTouchEvent() in Buzzer.cpp. Full rationale,
//  including why detection is by proxy via the touch controller, is in
//  Graphics.h - see "OPTIONAL DISPLAY GATE" there.
// ============================================================
bool displayDetected = false;

// ============================================================
//  PER-REGION DIRTY FLAGS
// ============================================================
volatile bool dirtyGauges = false;
volatile bool dirtyStatus = false;
volatile bool dirtyParticles = false;
volatile bool dirtyHeader = false;
volatile bool dirtyOutside = false;
volatile bool dirtyLD2410 = false;

void setDirtyGauges() {
  dirtyGauges = true;
  dirtyStatus = true;
}
void setDirtyParticles() {
  dirtyParticles = true;
  dirtyStatus = true;
}
void setDirtyHeader() {
  dirtyHeader = true;
}
void setDirtyOutside() {
  dirtyOutside = true;
}
void setDirtyLD2410() {
  dirtyLD2410 = true;
}
void setDisplayDirty() {
  dirtyGauges = true;
  dirtyStatus = true;
  dirtyParticles = true;
}

// ============================================================
//  TREND BUFFERS
// ============================================================
TrendBuffer trendCO2, trendHCHO, trendTVOC, trendPM25, trendTemp, trendHum;

void TrendBuffer::init() {
  memset(values, 0, sizeof(values));
  head = count = 0;
  initialised = true;
}
void TrendBuffer::push(float v) {
  if (!initialised) init();
  values[head] = v;
  head = (head + 1) % TREND_SAMPLES;
  if (count < TREND_SAMPLES) count++;
}
float TrendBuffer::latest() const {
  if (!count) return 0.0f;
  return values[head ? head - 1 : TREND_SAMPLES - 1];
}
int8_t TrendBuffer::trend() const {
  if (count < 4) return 0;
  uint8_t half = count / 2;
  float os = 0, ns = 0;
  for (uint8_t i = 0; i < half; i++)
    os += values[(head + TREND_SAMPLES - count + i) % TREND_SAMPLES];
  for (uint8_t i = half; i < count; i++)
    ns += values[(head + TREND_SAMPLES - count + i) % TREND_SAMPLES];
  float oa = os / half, na = ns / (count - half);
  float band = max(oa * 0.02f, 5.0f);
  if (na - oa > band) return  1;
  if (na - oa < -band) return -1;
  return 0;
}

// ============================================================
//  COLOUR HELPERS
// ============================================================
static uint16_t threshCol(float v, float good, float warn) {
  return (v <= good) ? COL_GOOD : (v <= warn) ? COL_WARN : COL_DANGER;
}
static uint16_t tempCol(float v) {
  if (v >= THRESH_TEMP_LOW_GOOD && v <= THRESH_TEMP_HIGH_GOOD) return COL_GOOD;
  if (v >= THRESH_TEMP_LOW_WARN && v <= THRESH_TEMP_HIGH_WARN) return COL_WARN;
  return COL_DANGER;
}
static uint16_t humCol(float v) {
  if (v >= THRESH_HUM_LOW_GOOD && v <= THRESH_HUM_HIGH_GOOD) return COL_GOOD;
  if (v >= THRESH_HUM_LOW_WARN && v <= THRESH_HUM_HIGH_WARN) return COL_WARN;
  return COL_DANGER;
}

// ============================================================
//  TREND ARROW
// ============================================================
static void drawTrendArrow(int16_t cx, int16_t cy, int8_t dir, uint16_t col) {
  tft.fillRect(cx - 6, cy - 7, 13, 15, COL_BG);
  if (dir > 0) tft.fillTriangle(cx, cy - 6, cx - 5, cy + 5, cx + 5, cy + 5, col);
  else if (dir < 0) tft.fillTriangle(cx, cy + 6, cx - 5, cy - 5, cx + 5, cy - 5, col);
  else              tft.fillTriangle(cx + 6, cy, cx - 3, cy - 5, cx - 3, cy + 5, col);
}
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

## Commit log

2026-07-25 Part of initial commit
    [BME280 Mount v1.stl, SCD40 Mount v1.stl, SFA40 Mount v4.stl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]
2026-07-25 Add Gerber file for PCB
2026-07-25 Remove PCBWAY reference
    GERBER may not be compatible and at this stage it is untested.
2026-07-26 Pre-Release Document Updates
    [BME280 Mount v1.stl, BME280 Mount v2.step, SCD40 Mount v1.stl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]
2026-07-27 Pre-Release Documents Update
    [Buzzer Mount v1.step]
2026-07-28 Pre-Release Update Part Images
    [WEM_BOM_Board1_2_PCB1_2_2026-07-27.xlsx]
2026-07-28 Pre-Release finalise BOM
    [WEM_BOM_Board1_2_PCB1_2_2026-07-27.xlsx]
2026-07-28 Pre-Release Doc Changes
    [WEM_BOM_Board1_2_PCB1_2_2026-07-27.xlsx]
2026-08-02 Add HA long-term statistics support to all numeric sensor entities
    Home Assistant only retains full-resolution state history for
    recorder.purge_keep_days (10 days by default). Beyond that window,
    entity History graphs fall back to the long-term statistics tables -
    but HA only populates those tables for entities that declare a
    state_class. None of WEM's HASensorNumber entities did, so every
    sensor's History graph went blank past 10 days regardless of the
    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
2026-08-02 Anchor v1.0.0 safety thresholds to residential air-quality guidance
    Set the v1.0.0 release safety thresholds to conservative,
    general-population defaults rather than occupational limits. Stance:
    alarm early, and leave it to the end user to raise a value to suit
    their own workshop - a conscious, owned decision on their part. WEM
    is a home device, so it anchors to residential guidance (WHO, US
    EPA), not to OSHA/NIOSH occupational limits, which assume a healthy
    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
2026-08-09 Change displayed "VENT" to "3D PRINTER VENT" ready for workshop venting section. Add comments to warning values so if an end user changes they can see the original value. Update main .ino name to sne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
2026-08-09 Review of STEP files for printing and add a 3MF file
    [LD2410B_Mount_Body_v3.step, LD2410B_Mount_Top_v3.step, WEM Enclosure Back v7.step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]
2026-09-20 SGP30: humidity compensation + baseline-to-HA export
    Two backlog items, developed and tested together:
    - Added updateSGP30HumidityCompensation(): feeds real humidity into the
    SGP30 (Adafruit_SGP30::setHumidity()) once a minute, sourced from the
    shared SHT40 temperature/humidity globals with no new I2C reads of its
    own. Gated on sht40Detected + freshness (STALE_MED_MS) so a missing or
    stalled SHT40 can't silently feed a stale value forever. Previously the
    chip ran on its fixed internal default with zero real compensation -
    confirmed as a genuine source of error via a logged TVOC/RH correlation
    on an otherwise fresh, NVS-reset chip.
    - Added two Home Assistant entities, SGP30_eC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
    [LD2410B Mount v3.f3d, LD2410B_Mount_v3.3mf, WEM Enclosure v17.3mf]

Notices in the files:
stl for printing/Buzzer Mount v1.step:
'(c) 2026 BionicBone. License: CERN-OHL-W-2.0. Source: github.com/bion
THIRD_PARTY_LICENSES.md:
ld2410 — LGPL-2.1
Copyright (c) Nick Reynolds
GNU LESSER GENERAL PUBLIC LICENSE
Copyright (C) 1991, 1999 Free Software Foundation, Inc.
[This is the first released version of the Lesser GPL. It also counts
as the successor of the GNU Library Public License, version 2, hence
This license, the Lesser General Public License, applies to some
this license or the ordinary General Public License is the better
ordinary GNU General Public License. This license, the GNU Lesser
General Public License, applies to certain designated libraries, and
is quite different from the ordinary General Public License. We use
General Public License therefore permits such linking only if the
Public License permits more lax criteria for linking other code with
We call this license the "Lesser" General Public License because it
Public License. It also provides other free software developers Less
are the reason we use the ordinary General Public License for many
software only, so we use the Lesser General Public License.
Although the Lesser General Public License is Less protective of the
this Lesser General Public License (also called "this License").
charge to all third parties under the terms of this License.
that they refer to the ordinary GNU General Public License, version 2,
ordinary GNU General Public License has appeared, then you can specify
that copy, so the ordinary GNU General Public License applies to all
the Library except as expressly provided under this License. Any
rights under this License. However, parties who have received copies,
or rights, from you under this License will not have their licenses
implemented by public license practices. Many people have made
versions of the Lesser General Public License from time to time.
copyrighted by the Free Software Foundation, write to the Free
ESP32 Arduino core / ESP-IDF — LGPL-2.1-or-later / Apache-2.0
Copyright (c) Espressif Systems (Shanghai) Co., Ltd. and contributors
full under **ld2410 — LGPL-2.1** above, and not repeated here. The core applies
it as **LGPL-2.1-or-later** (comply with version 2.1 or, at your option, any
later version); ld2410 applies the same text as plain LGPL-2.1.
